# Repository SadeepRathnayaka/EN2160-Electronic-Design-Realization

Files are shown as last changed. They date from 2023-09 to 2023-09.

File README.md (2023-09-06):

# Semester 4 University Project - My Individual Work

## Introduction

Welcome to my semester 4 university project! This project represents my individual work, and it comes with several important features:

- **On/Off Switch:** There's a main switch that turns the product on and off.
- **Multimeter and Power Supply Modes:** Another switch allows you to switch between two modes: multimeter and 5V power supply.
- **Rotary Controls:** You'll find two rotary switches designed for mode selection and adjusting the ohmmeter's scale.
- **LED Display:** All the important readings are conveniently displayed on an LED screen.
- **Rechargeable Battery:** What makes this product special is its built-in rechargeable battery system. Say goodbye to constant battery replacements; this product includes an integrated charger mechanism.

<p align="center">
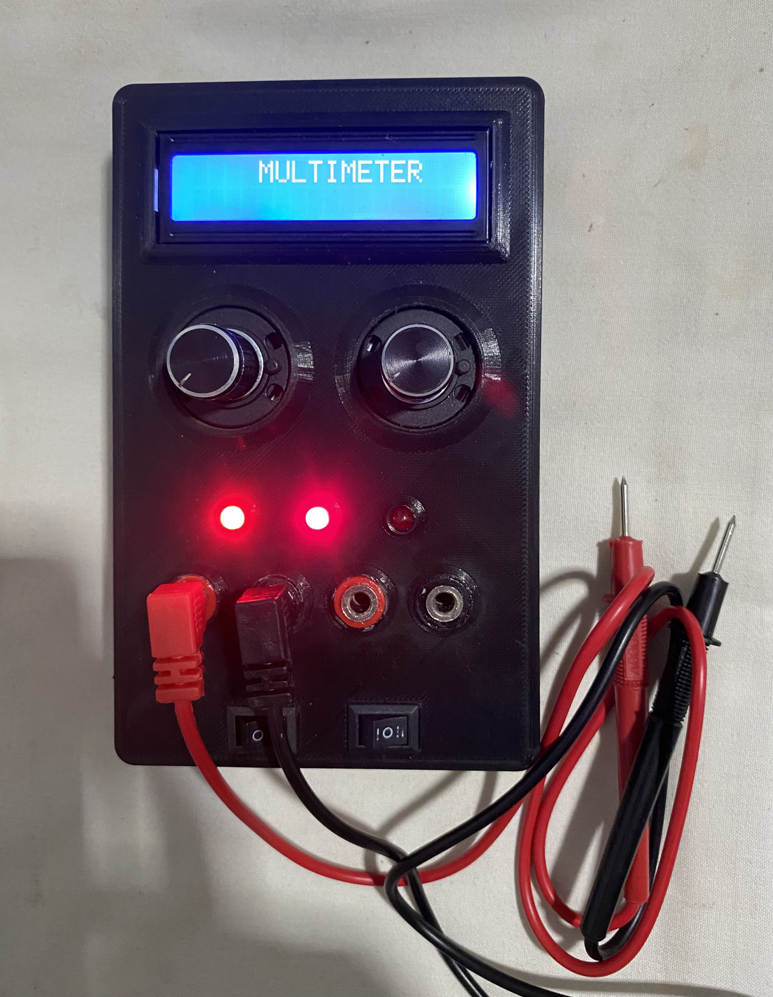
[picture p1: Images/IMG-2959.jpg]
  
</p>

## Specifications

- This product functions primarily as a multimeter and can also serve as a 5V DC power supply.
- The multimeter offers four distinct modes:

    1. Voltmeter
       - Measurement range: 0V to 50V

    2. Ammeter
       - Measurement range: 1mA to 2A

    3. Ohmmeter
       - Measurement range: 0 ohms to 1M ohms
       - It includes four resistance scales:
           - 0 to 1K ohms
           - 1K to 100K ohms
           - 100K to 400K ohms
           - 400K to 1M ohms

    4. Continuity Checker

- No need to change probes when switching to ammeter mode.
- This product features a charging capability, and when fully charged, it can operate continuously for up to 12 hours.
- A two-way switch allows easy mode switching between multimeter and power supply.
- Weight: 500g
- Dimensions: 13cm × 9cm × 2.5cm

  ## What You Can Find Here

- Component List
- Block Diagram
- Circuit Diagrams
- Schematics Designs
- PCB Designs
- Enclosure Design

*For more information, feel free to explore all the files and data in my repository. I've included comprehensive documentation, source code, and additional resources for a deeper dive into this project. Your feedback and contributions are highly appreciated.*

## Component List

- Atmega328p Microcontroller
- 3P4T Rotary Switches
- 16*2 LCD Display
- Single Pole Double Throw Switch
- On-Off Switch
- 1200mAh LiPo Battery
- TP4056 Charging Module
- MT3608 Boost Converter

## Block Diagram

<p align="center">
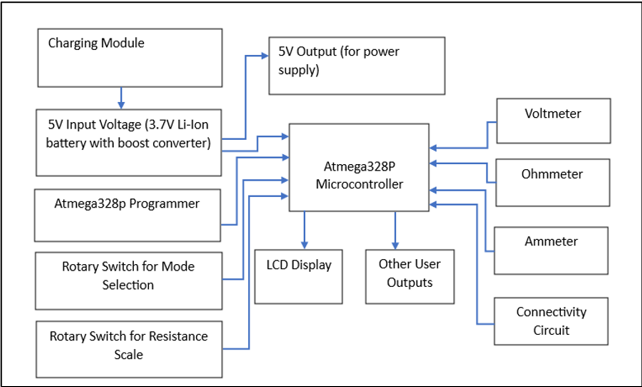
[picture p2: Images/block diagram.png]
  
</p>

## Circuit Diagrams

### Voltemeter
<p align="center">
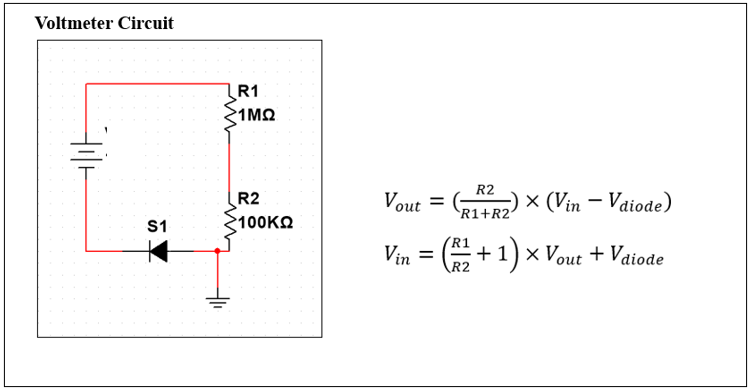
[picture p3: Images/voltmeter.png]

</p>

### Ohmmeter
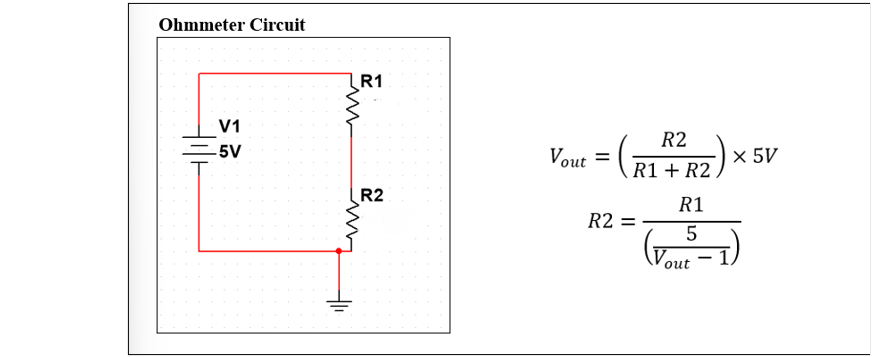
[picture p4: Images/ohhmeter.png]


### Ammeter
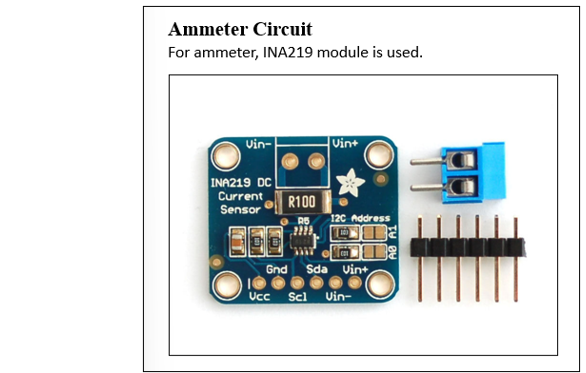
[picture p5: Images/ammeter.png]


## Schematic Designs 
<p align="center">
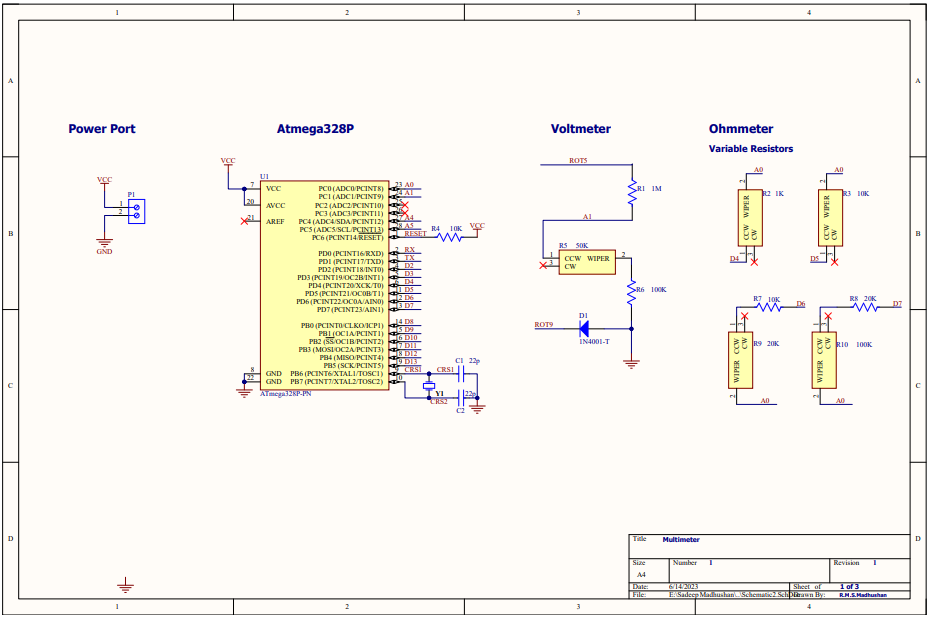
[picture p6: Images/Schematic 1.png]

</p>

<p align="center">
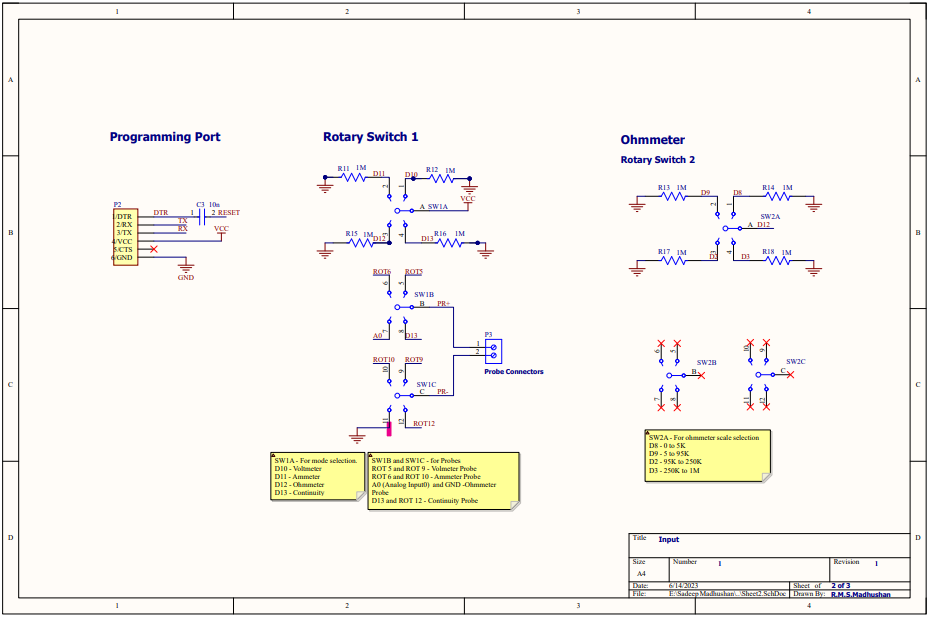
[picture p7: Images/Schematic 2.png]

</p>

<p align="center">
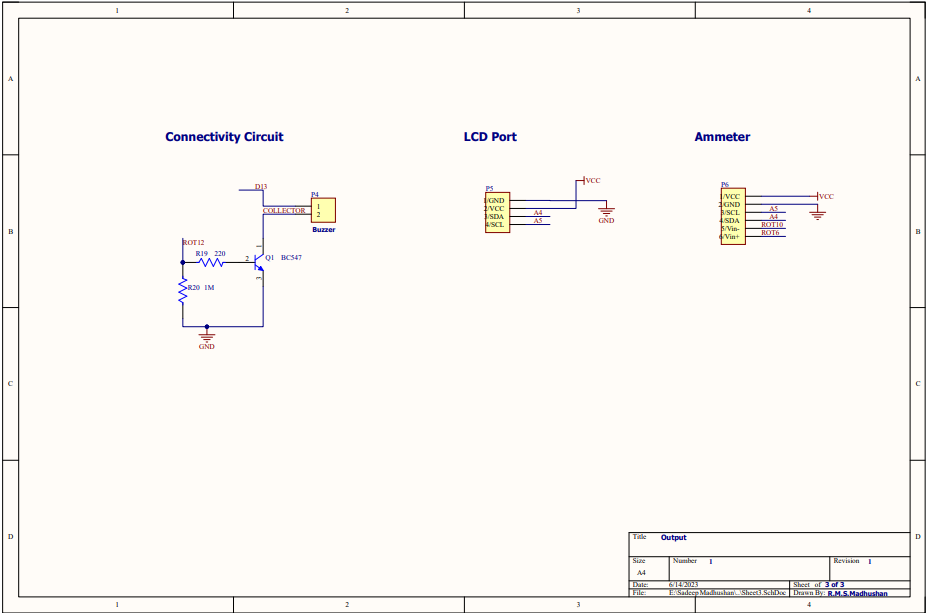
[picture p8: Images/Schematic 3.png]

</p>

## PCB Designs

<p align="center">
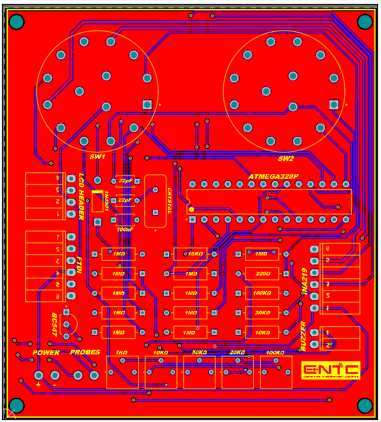
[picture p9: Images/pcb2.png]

</p>

<p align="center">
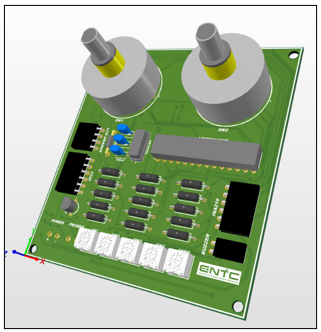
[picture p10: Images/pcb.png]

</p>

<p align="center">
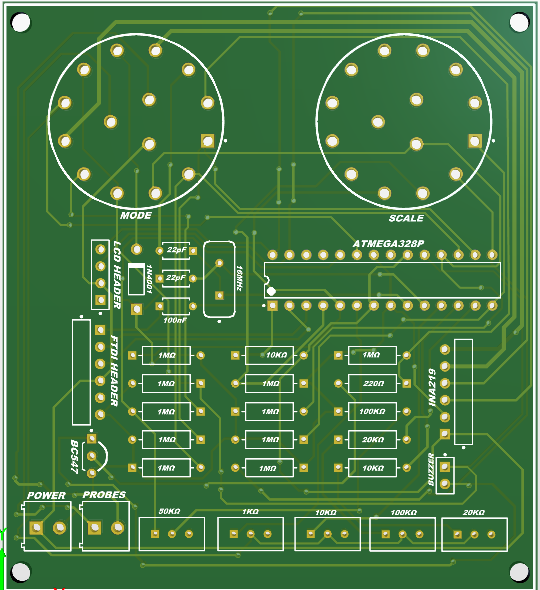
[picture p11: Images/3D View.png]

</p>

<p align="center">
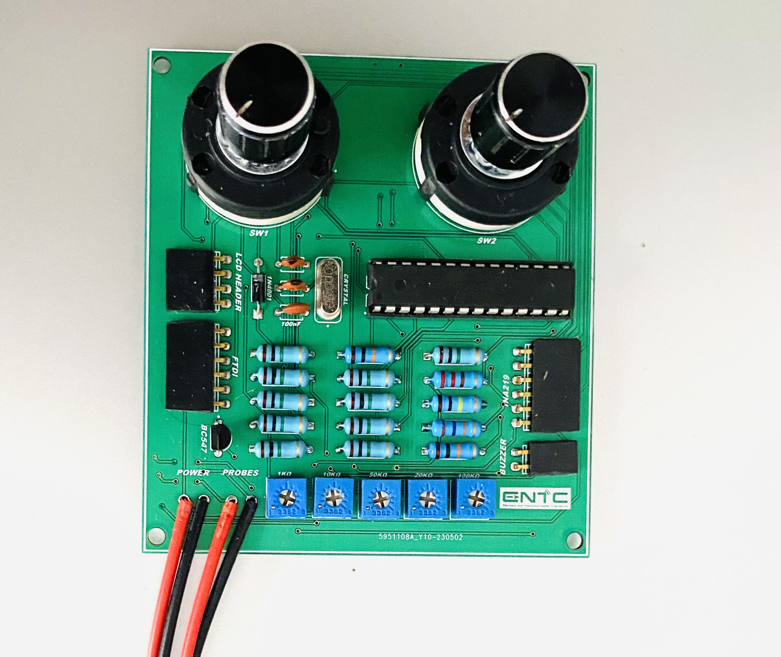
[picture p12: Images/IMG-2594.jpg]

</p>

## Enclosure Designs

<p align="center">
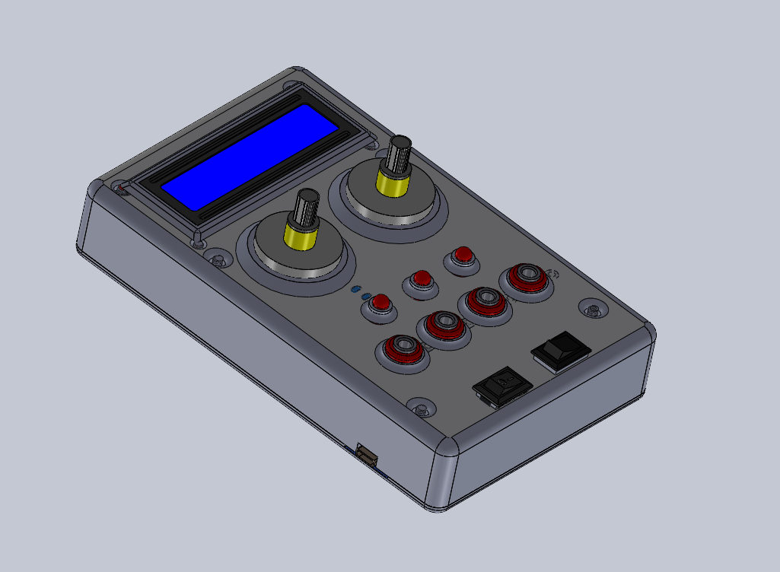
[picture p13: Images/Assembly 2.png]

</p>

<p align="center">
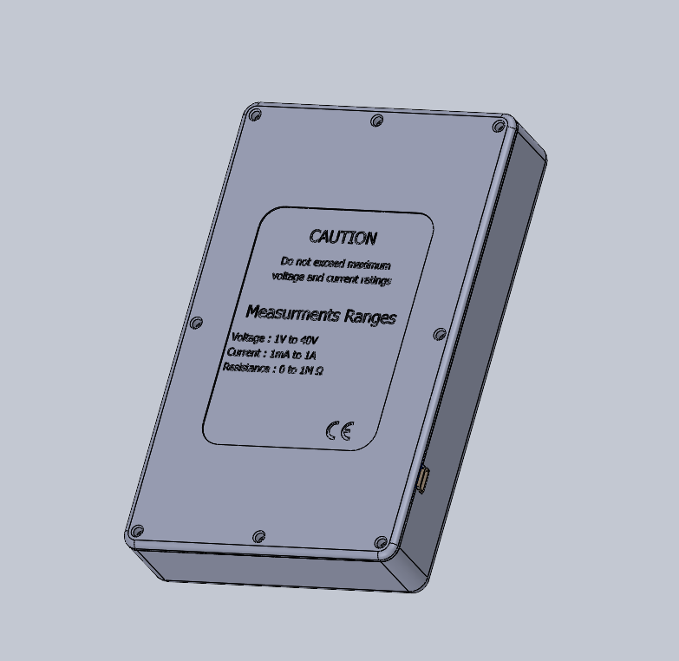
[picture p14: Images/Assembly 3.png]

</p>

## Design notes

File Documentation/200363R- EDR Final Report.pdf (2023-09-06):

1 | P a g e

## Department of Electronics and Telecommunication Engineering

Faculty of Engineering

University of Moratuwa

EN2160 Electronic Design Realization

Final Report

Madhushan R.M.S.

200363R

2 | P a g e

## Table of Contents

3 | P a g e

4 | P a g e

## General Information

Overview

The objective of the project was to create a commercially viable electronic product, incorporating novel functionalities to fulfill an existing demand. It is decided to make a digital multimeter which has a DC power supply compatibility as an extra feature. A multimeter, short for "multiple meter," is an indispensable tool in the realm of electrical and electronic measurements. This ingenious device serves as an all-in-one instrument, combining the functionalities of several meters into a single, compact unit. Its versatility makes it an essential companion for technicians, engineers, electricians, hobbyists, and anyone dealing with electrical circuits and systems.

In this fast-paced world of electronics and electrical engineering, the multimeter remains an enduring and vital instrument. As technology continues to evolve, these devices evolve too, incorporating innovative features and improvements to meet the ever-changing demands of the modern era. Whether you're a seasoned professional or an enthusiastic beginner, a multimeter is an invaluable asset, empowering you to confidently explore the intricacies of the electrical world.

Functionality

The focal attributes of this product comprise a primary switch and a two-way switch. The primary switch serves the purpose of activating or deactivating the product, while the second switch is responsible for seamlessly transitioning between the multimeter and 5V power supply modes. Additionally, the product incorporates two rotary switches, where one is designated for mode selection and the other is dedicated to adjusting the ohmmeter's scale. The readings obtained from the various functionalities are conveniently displayed through the utilization of an LED display. Notably, this product boasts a rechargeable battery system, eliminating the necessity for battery replacement, as it comes equipped with an integrated charger mechanism.

5 | P a g e

### Specifications

- This product is mainly a multimeter. Also this can be used as a 5V DC power supply.
- Multimeter has four modes.
1. Voltmeter
- Measurement range = 0V to 50V
2. Ammeter
a. Measurement range = 1mA to 2A
3. Ohmmeter
a. Measurement range = 0 ohm to 1M ohm
b. There are four resistance scales.
c. 0 to 1K ohm
d. 1K to 100K ohm
e. 100K to 400K ohm
f. 400K to 1M ohm
4. Continuity checker
- Probes do not have to change when it is working as an ammeter.
- This product has a charging feature.
- Once it is fully charged, it can be used 12 hours straight.
- There is a two way switch to change the mode between multimeter and power supply.
- weight = 500g
- Dimensions = 13cm × 9cm × 2.5cm

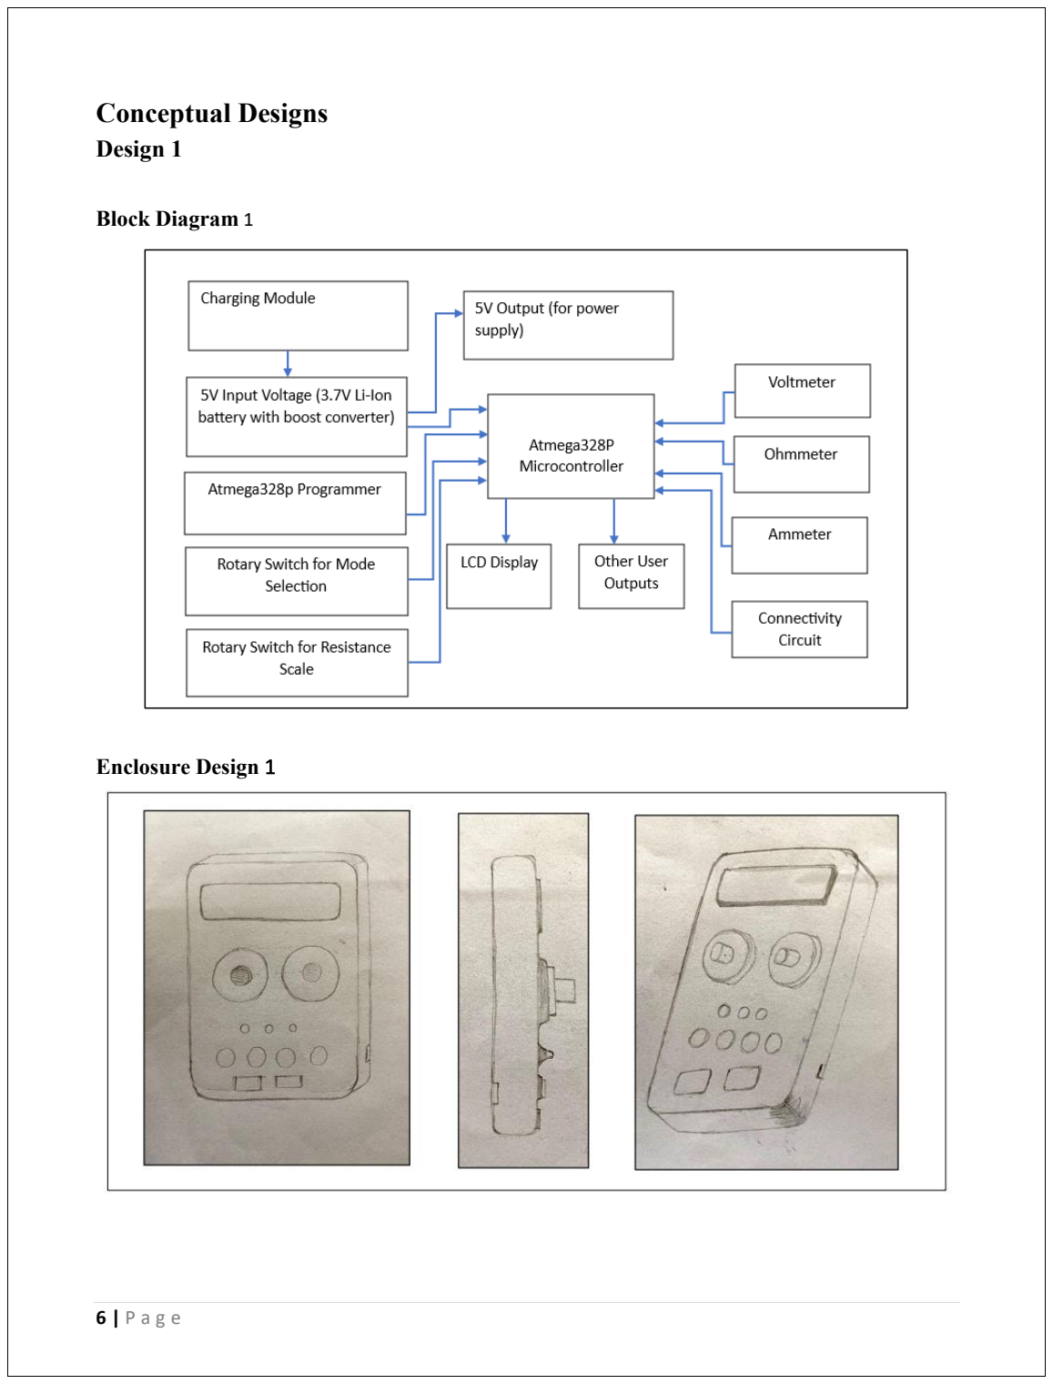
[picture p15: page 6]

6 | P a g e

### Conceptual Designs

Design 1

Block Diagram 1

Enclosure Design 1

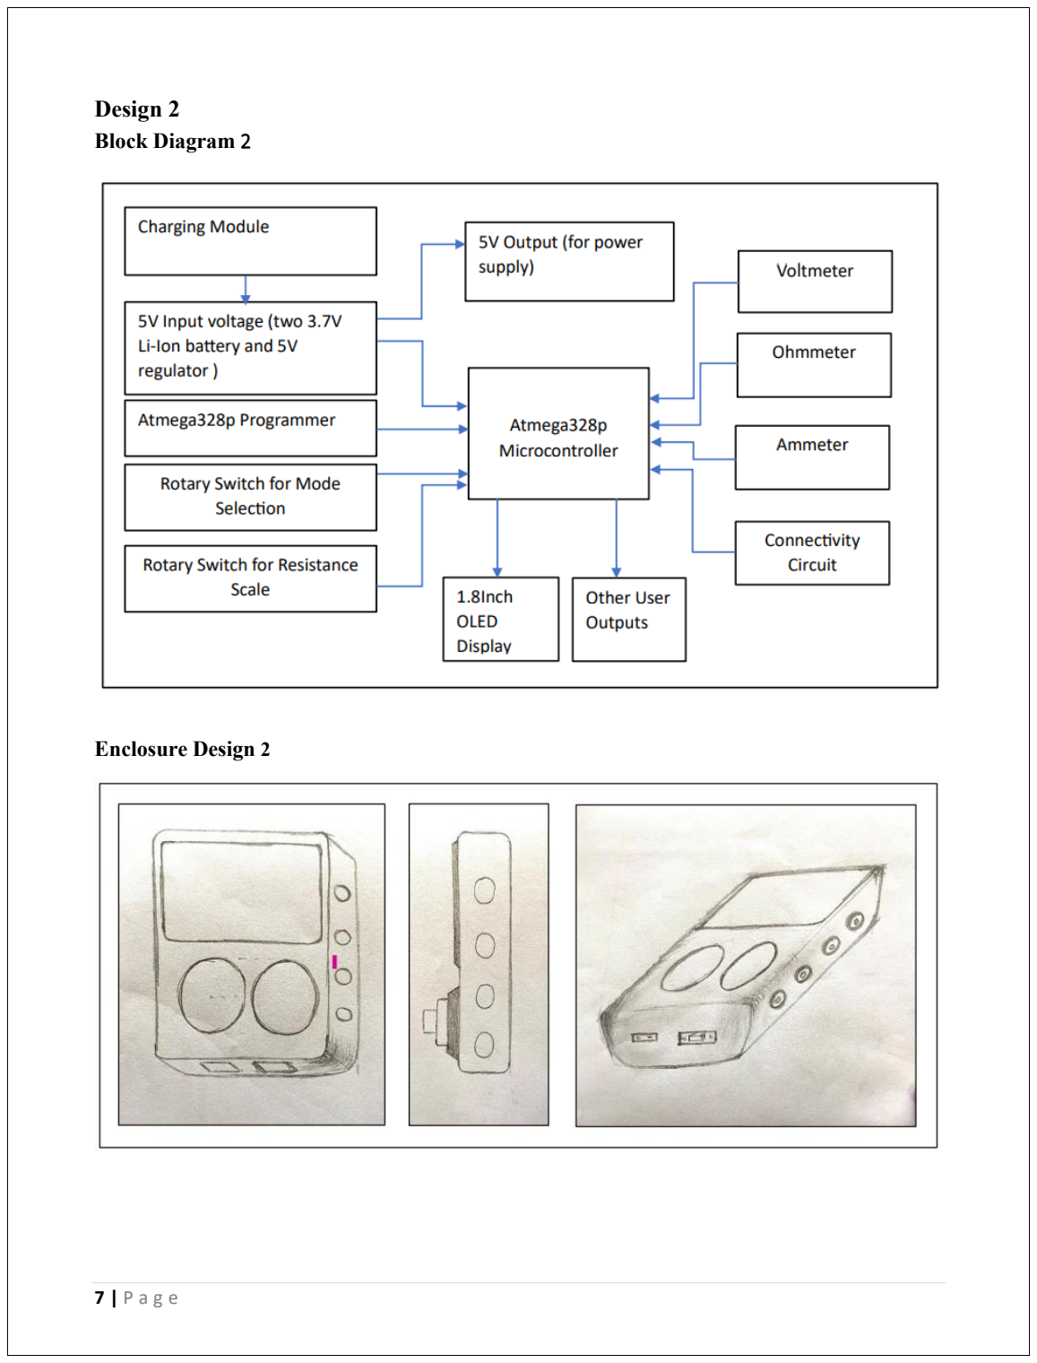
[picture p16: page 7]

7 | P a g e

Design 2
Block Diagram 2

Enclosure Design 2

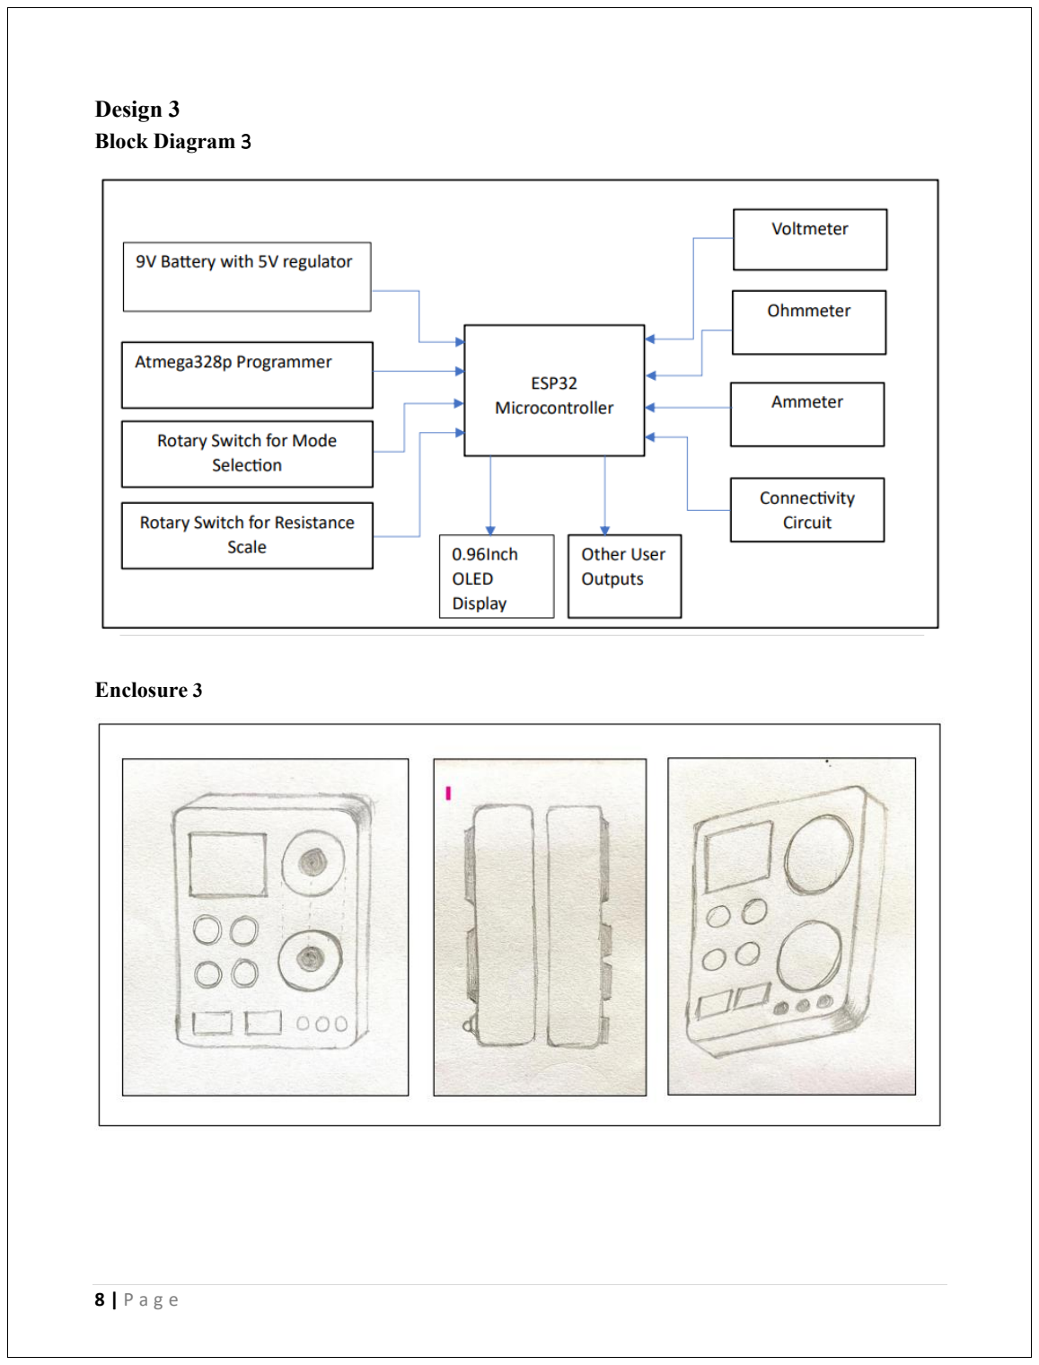
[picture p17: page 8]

8 | P a g e

Design 3
Block Diagram 3

Enclosure 3

9 | P a g e

### Comparison of Block Diagram 1 and 2

- Instead of one Li-Ion battery, two batteries are added to block diagram 2. Therefore, the total power that the circuit can utilize is higher than the 1st block diagram.
- Instead of using buck/boost converter, 5V voltage regulator is used since the regulator is inexpensive when compared buck/boost converter which is used in block diagram 1.
- In this design, a much larger OLED display is used compared to block diagram 1.

### Comparison of Block Diagram 1 and 3

- 5V Power supply option is removed in the design.
- The charging feature is removed.
- One 9V battery is used compared to block diagram 1.
- A smaller OLED display is used in this block diagram.
- Buck/boost converter is not used to reduce the cost.

10 | P a g e

Evaluation
Evaluation of Block Diagram Criteria :
1) Functionality
2) Accuracy
3) User Friendliness
4) Cost
5) Power Consumption
6) Reliability
7) Compatibility – (Capability of replacing device or systems that perform the same process or part of the process)
| Block Diagram 1 | Block Diagram 2 | Block Diagram 3
Functionality | 10 | 9 | 9
Accuracy | 9 | 8 | 8
User Friendliness | 9 | 7 | 7
Cost Effectiveness | 8 | 7 | 9
Power Efficiency | 8 | 8 | 9
Reliability | 9 | 9 | 9
Compatibility | 7 | 7 | 7
Total | 59 | 55 | 58

Evaluation of Enclosure Design Criteria :

1) Durability
2) Attractiveness
3) Cost Effectiveness
4) User Safety – Prevention from electric leakage
5) Compatibility – Capability of attaching the device to a certain place
6) Repairability
7) Weight and Hardness
| Enclosure 1 | Enclosure 2 | Enclosure 3
Durability | 9 | 9 | 9
Attractiveness | 8 | 7 | 7
Cost Effectiveness | 8 | 7 | 8
User Safety | 8 | 8 | 8
Compatibility | 8 | 7 | 8
Repairability | 8 | 5 | 7
Weight and Hardness | 8 | 8 | 8
Total | 57 | 51 | 55
According to the evaluation, block diagram 1 and enclosure design 1 has been chosen.

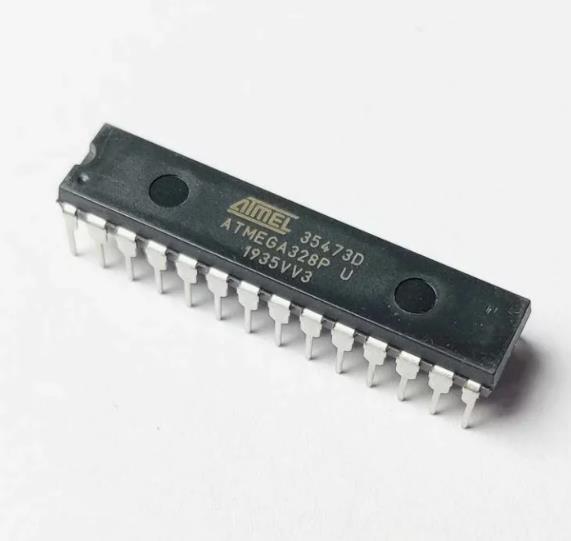
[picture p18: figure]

11 | P a g e

## Components

Atmega328P Microcontroller

The ATmega328P is a widely used 8-bit microcontroller from the AVR family, manufactured by Atmel (now Microchip Technology). It offers a versatile and efficient solution for a wide range of embedded systems and DIY electronics projects. With a clock speed of up to 20 MHz, it can handle tasks quickly and precisely. The microcontroller comes equipped with 32KB of Flash memory for storing program code, 2KB of SRAM for temporary data storage, and 1KB of EEPROM for non-volatile data storage. Its GPIO pins allow for flexible interfacing with external devices, while the built-in 10-bit ADC enables the conversion of analog signals to digital values. Additionally, the ATmega328P features multiple timers and counters, which are valuable for generating accurate timing, PWM signals, and event counting. Its popularity and ease of use make it a favored choice among hobbyists, engineers, and developers seeking a reliable microcontroller for their projects.

All voltmeter, ammeter, ohmmeter, continuity checker circuits are connected to the relevant pins of this microcontroller. Once it is set to the appropriate state for the ammeter, volmeter, ammeter ohmmeter, continuity checker, the microcontroller will send the reading to the display.

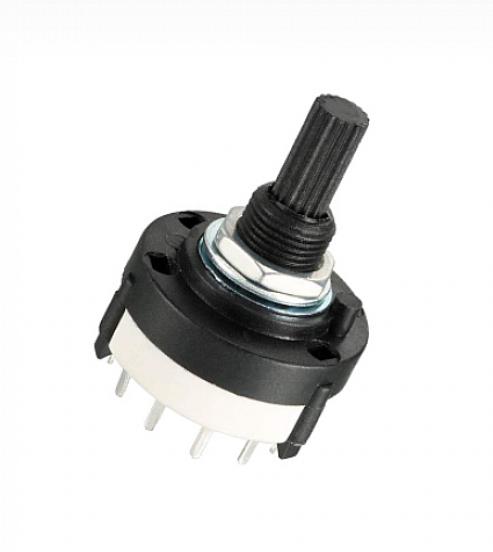
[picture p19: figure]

12 | P a g e

Rotary Switch

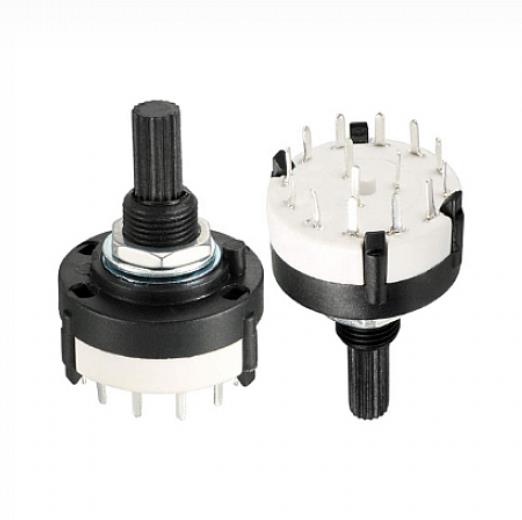
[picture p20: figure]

The 3P4T switch is a rotary switch commonly used in electronics. It has three poles, allowing control of three separate circuits, and four positions, enabling the selection of different circuit combinations with a single actuator. This switch is frequently employed in devices like audio equipment and electronic instruments for straightforward and reliable circuit switching.

In this product, two 3 pole 4 state switches are used. One is for multimeter modes and for the other one is for resistance scale.

The mode selection rotary switch has four modes.

1. Voltmeter
2. Ammeter
3. Ohmmeter
4. Continuity Checker

When the modes are changed, corresponding probes connection also changes accordingly. Therefore the user does not have to change the probes when the mode is being changed.

Resistance scale rotary switch has four scales.

1. 1K ohm
2. 100K ohm
3. 400K ohm
4. 1M ohm

13 | P a g e

LCD Display

The 16x2 LCD display is a widely used alphanumeric display module in the field of electronics and embedded systems. It consists of 16 columns and 2 rows, providing a total of 32 characters (16 characters per row) that can be displayed at once. Each character position is typically composed of a 5x8 dot matrix, allowing the display of letters, numbers, symbols, and simple graphics.

Single Pole Double Throw Switch

A Single-Pole, Double-Throw (SPDT) switch is a basic and commonly used type of electrical switch. It consists of a single input terminal (pole) and two output terminals (throws). When in the "ON" position, the common terminal connects to one of the two output terminals, and when in the "OFF" position, it disconnects from the first output and connects to the second one. This simple but versatile configuration allows SPDT switches to toggle between two different circuits, making them suitable for various applications, such as controlling lights, motors, and electronic devices.

This switch is used to change the mode between multimeter and 5V DC power supply.

14 | P a g e

Battery

The LiPo (Lithium Polymer) 1200mAh battery is a compact and lightweight rechargeable power source widely used in portable electronics and hobbyist projects. With a capacity of 1200 milliampere-hours (mAh), it can supply a steady electric current of 1.2 Amps for one hour, or proportional current over a longer duration. This outputs 3.7V.

Instead of 18650 Li-Ion 1200mAh battery, it is decided use this battery. Main reason for that is the size of this battery. It is a compact battery so that the product size also can be more small.

Charging Module

The TP4056 is a popular and widely used single-cell lithium battery charging module. It is designed to charge lithium-ion (Li-ion) and lithium-polymer (LiPo) batteries safely and efficiently. This compact module integrates a charging chip, power management components, and status indicator LEDs into a single package, making it convenient for charging applications. Therefore this module has been chosen for the charging module for the device.

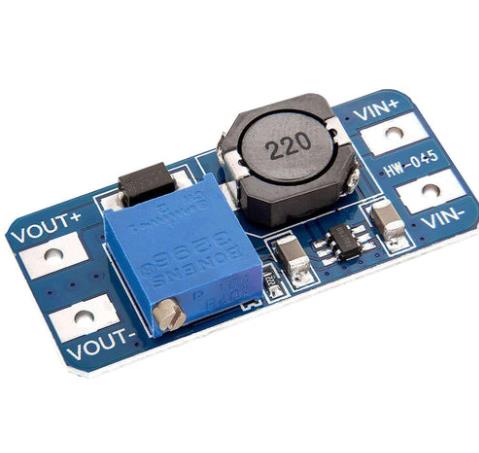
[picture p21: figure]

15 | P a g e

Boost Converter

The MT3608 is a versatile and widely used DC-DC boost converter module designed to step up voltage levels efficiently. Since Li-Po battery only output 3.7V it should be convert to 5V. In order to do that, this module has been chosen.

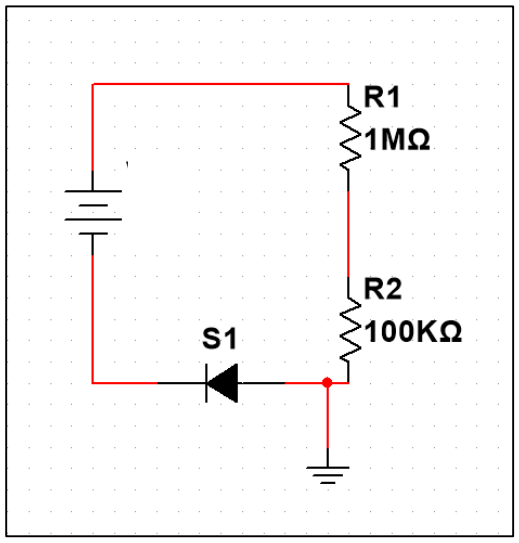
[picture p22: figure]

16 | P a g e

## Circuit Diagrams

Voltmeter Circuit

- In this circuit, R1 and R2 are chosen in such a way that the voltage measuring range can be

maintained around 50V.

- 1N4001 diode is used to block the current to the other direction.
- Here V1 act as the voltage source we want to measure the voltage.
- When V1 is set, there is a voltage drop across the R2 resistor and that voltage drop is measured

from analog input pin from atmega328p microcontroller.

- After taking that Vout value, according to the above calculation Vin can be found.

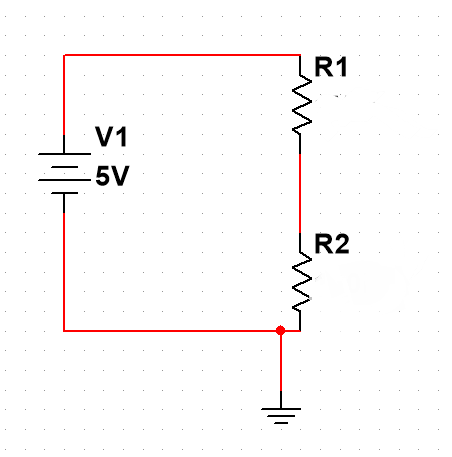
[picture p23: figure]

17 | P a g e

Ohmmeter Circuit

- R2 is the unknown resistor.
- There are four R1 resistors chosen according to various scale.
- 1K, 10K, 50K and 100K are the R1 resistor values.
- According to the R2 value user can set the corresponding R1 value with a rotary switch and then

more precisely resistance can be measured.

- 5V is being supplied from the atmega328p microcontroller.
- After supplying that voltage, there is a corresponding voltage drop across R2 and that will be

measured from analog input of the atmega328p microcontroller.

- Then according to the above calculation, R2 can be found.

18 | P a g e

Ammeter Circuit
For ammeter, INA219 module is used.

The primary functionality of the INA219 is current sensing. It is specifically designed to accurately measure the current flowing through a load in electrical systems. This is achieved through a high-side current shunt resistor incorporated within the IC.

When current flows through the load, a voltage drop occurs across the shunt resistor. The INA219 measures this voltage drop with high precision. By utilizing Ohm's law (V = I * R), where V is the voltage across the shunt resistor, I is the current flowing through the load, and R is the resistance of the shunt, the INA219 calculates the current value.

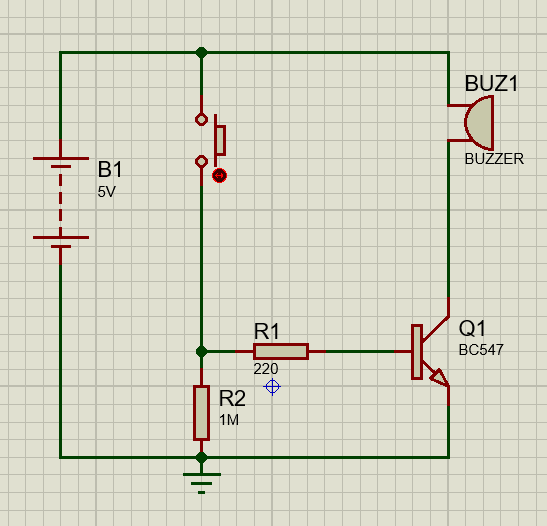
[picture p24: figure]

19 | P a g e

Continuity Checker Circuit

- Instead of push button, two probes are set there.
- therefore when there is connection between those two probes, circuit will be fully connected.
- Then, there will be base current and the transistor will act as a closed switch and buzzer will be

on.

## Schematic Design

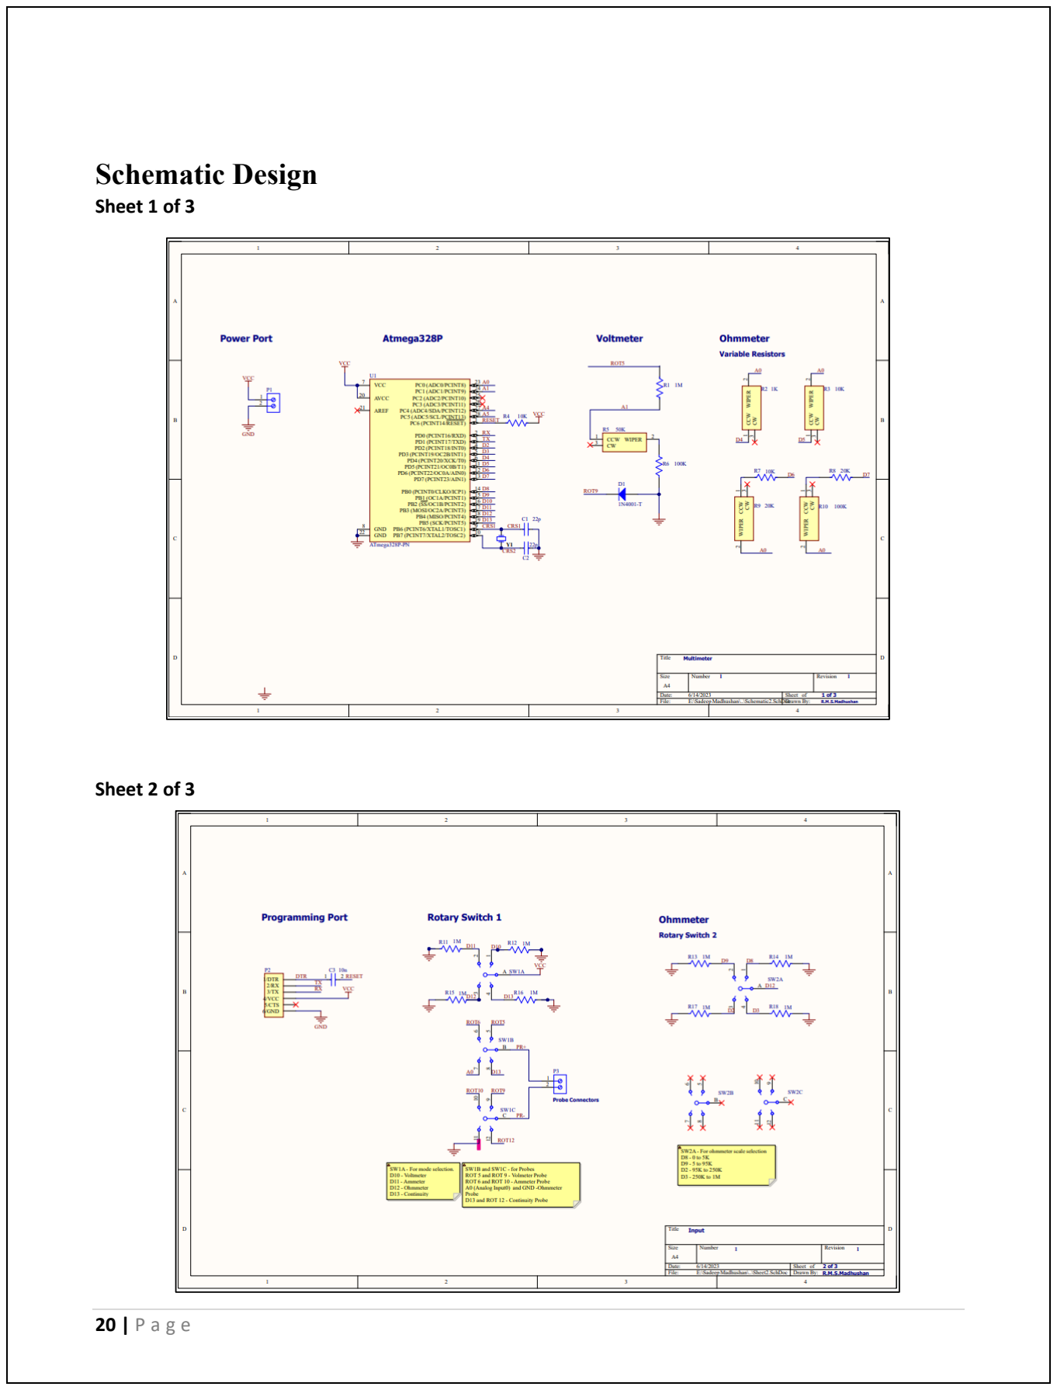
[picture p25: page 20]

20 | P a g e

Sheet 1 of 3

Sheet 2 of 3


21 | P a g e

Sheet 3 of 3

22 | P a g e

## Printed Circuit Board

Gerber Files Details
Top Layer Gerber Data

Top Overlay Gerber Data

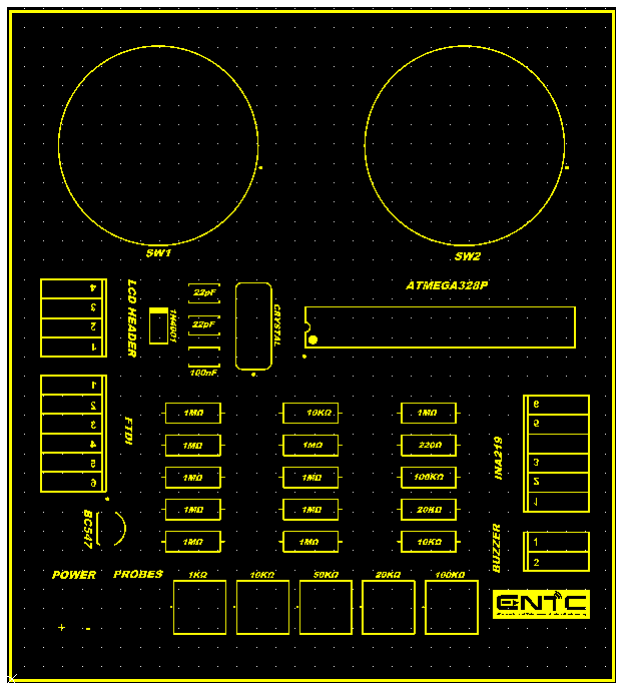
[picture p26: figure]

23 | P a g e

Top Solder Mask Gerber Data

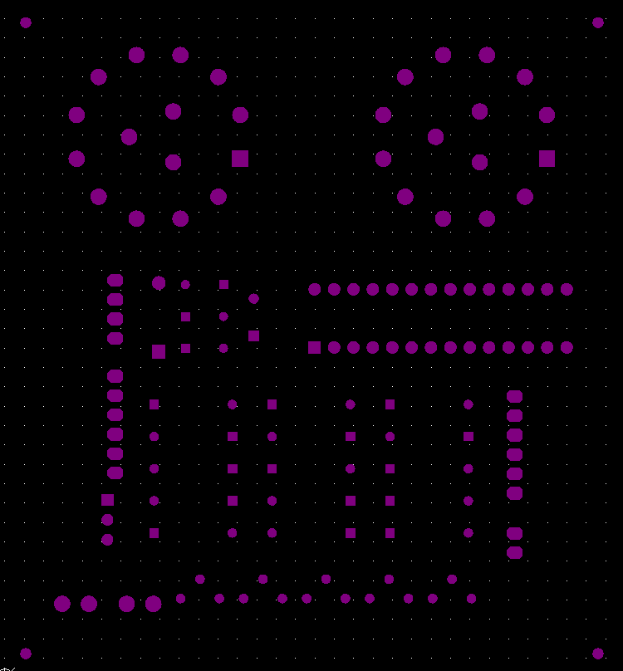
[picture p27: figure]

Bottom Layer Gerber Data

24 | P a g e

Bottom Solder Mask Gerber Data

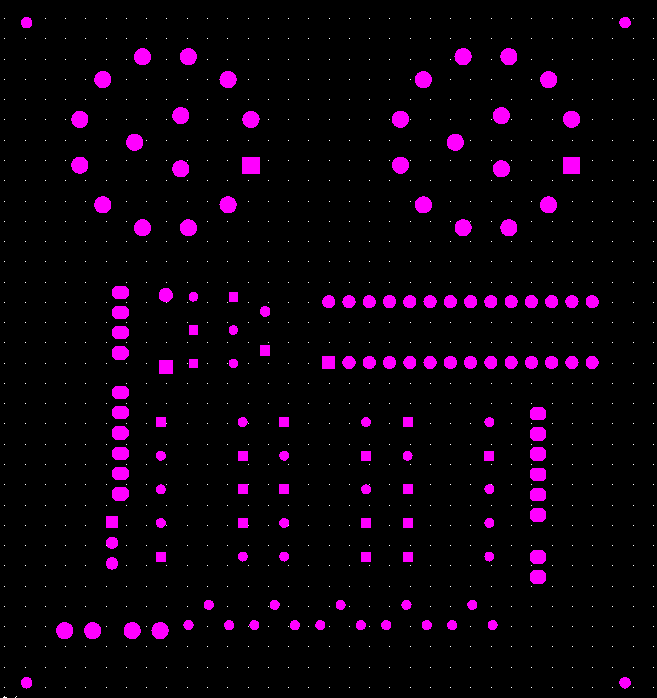
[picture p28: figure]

Drill Drawing Layer Pair Gerber Data

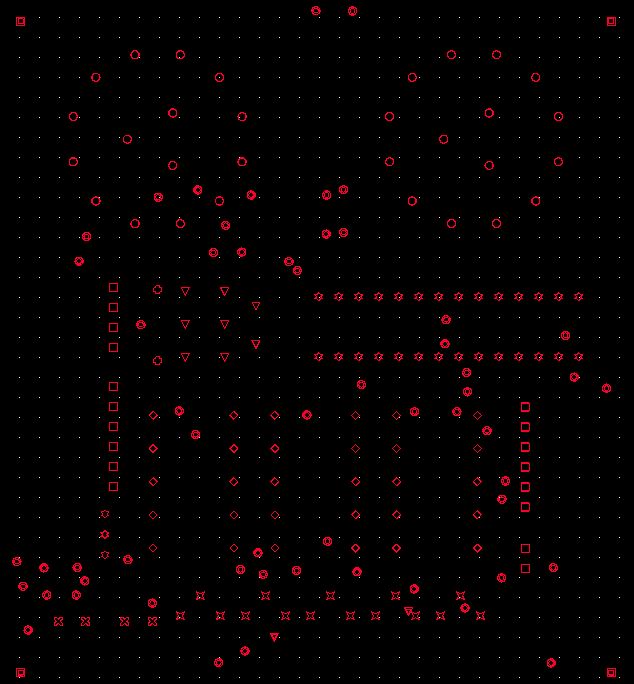
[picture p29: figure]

25 | P a g e

2D View

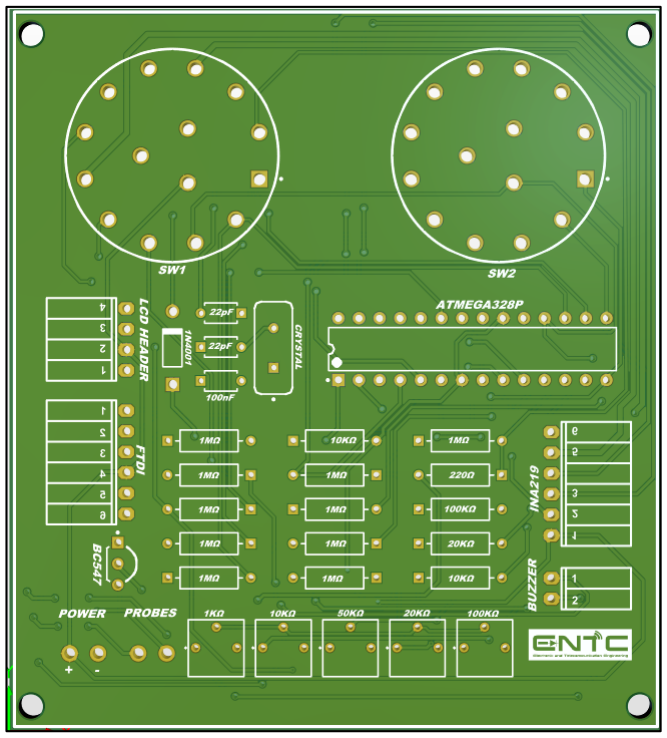
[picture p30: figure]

26 | P a g e

3D View

After Soldering:

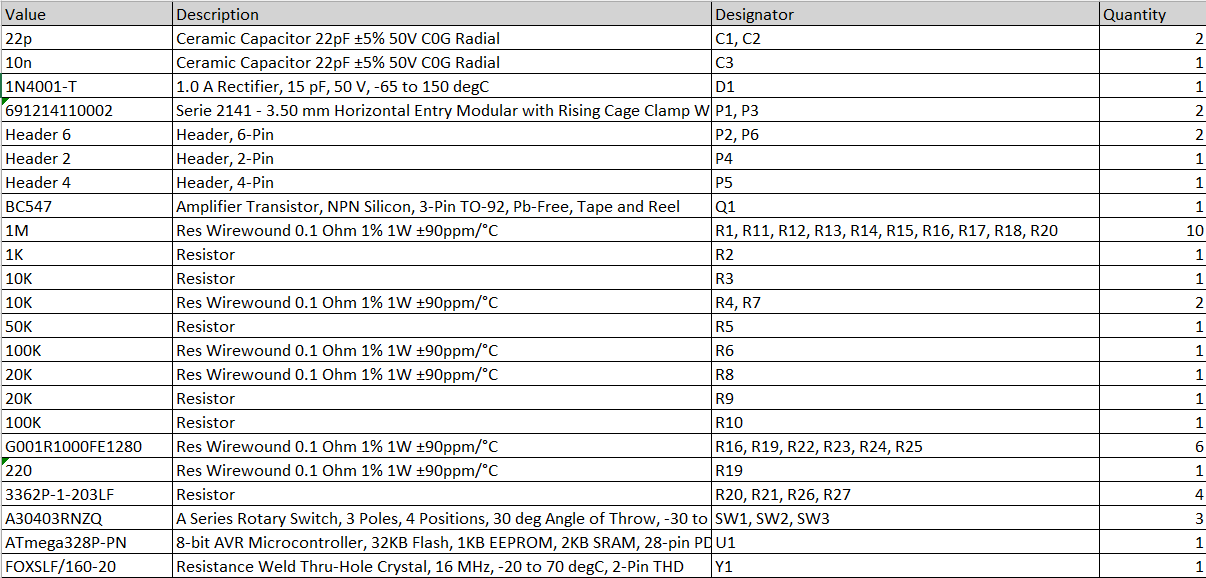
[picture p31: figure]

27 | P a g e

Bill of Materials

28 | P a g e

## Suppliers and Manufacturers

Component | Quantity | Manufacturer | Supplier | Price (LKR)
22pF Capacitor | 2 | | Local Supplier | 10
1M Resistors | 10 | | Local Supplier | 50
1K Resistors | 1 | | Local Supplier | 5
10K Resistors | 3 | | Local Supplier | 15
20K Resistors | 1 | | Local Supplier | 5
50K Resistors | 1 | | Local Supplier | 5
100K Resistors | 1 | | Local Supplier | 5
1K Preset Potentiometer | 1 | Bochen | LCSC Electronics | 20
10K Preset Potentiometer | 1 | Bochen | LCSC Electronics | 20
20K Preset Potentiometer | 1 | Bochen | LCSC Electronics | 20
50K Preset Potentiometer | 1 | Bochen | LCSC Electronics | 20
120K Preset Potentiometer | 1 | Bochen | LCSC Electronics | 20
Atmega328P | 1 | Microchip Technology | Mouser Electronics | 2000
16MHz Oscillator | 1 | | Local Supplier | 20
BC547 Transistor | 1 | | Local Supplier | 5
3P4T Rotary Switch | 2 | | Local Supplier | 600
1N4001 Diode | 1 | | Local Supplier | 5
INA219 Sensor | 1 | Adafruit | Mouser Electronics | 3000
TP4056 Module | 1 | | Local Supplier | 160
3.7V Li-Po Battery | 1 | TinyCircuits | Mouser Electronics | 2000
MT3608 Boost Converter | 1 | | Local Supplier | 280
LCD Display | 1 | | Local Supplier | 700
SPDT Switch | 1 | | Local Supplier | 20
On-off switch | 1 | | Local Supplier | 10
JST cables and other wires | | | Local Supplier | 300

## Enclosure

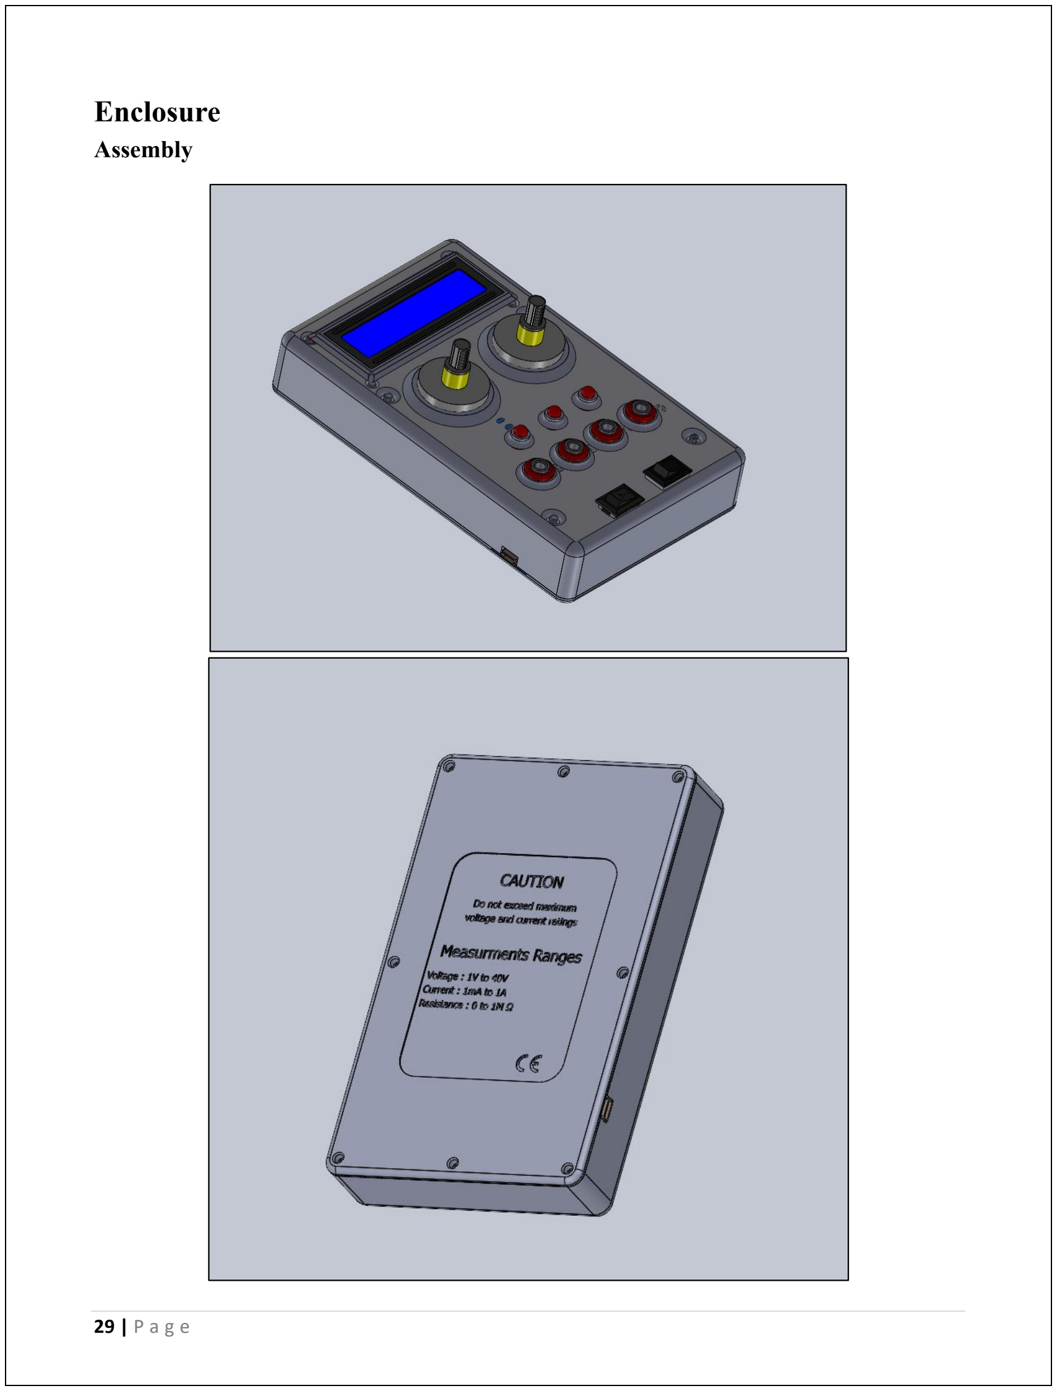
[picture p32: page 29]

29 | P a g e

Assembly

30 | P a g e

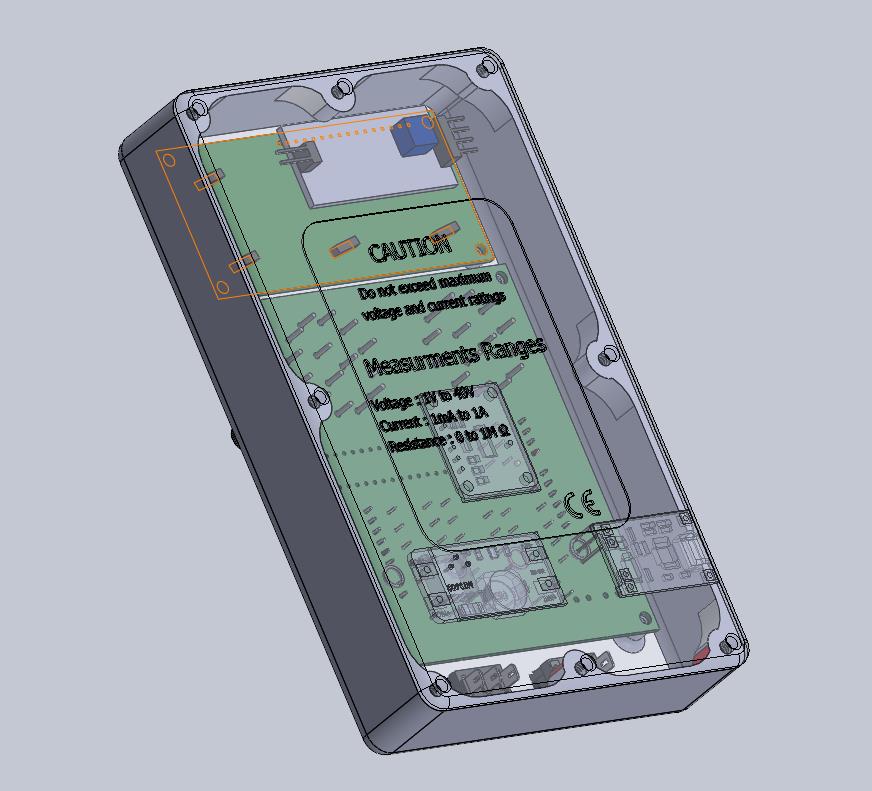
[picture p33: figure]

31 | P a g e

Top Cover

Bottom Cover

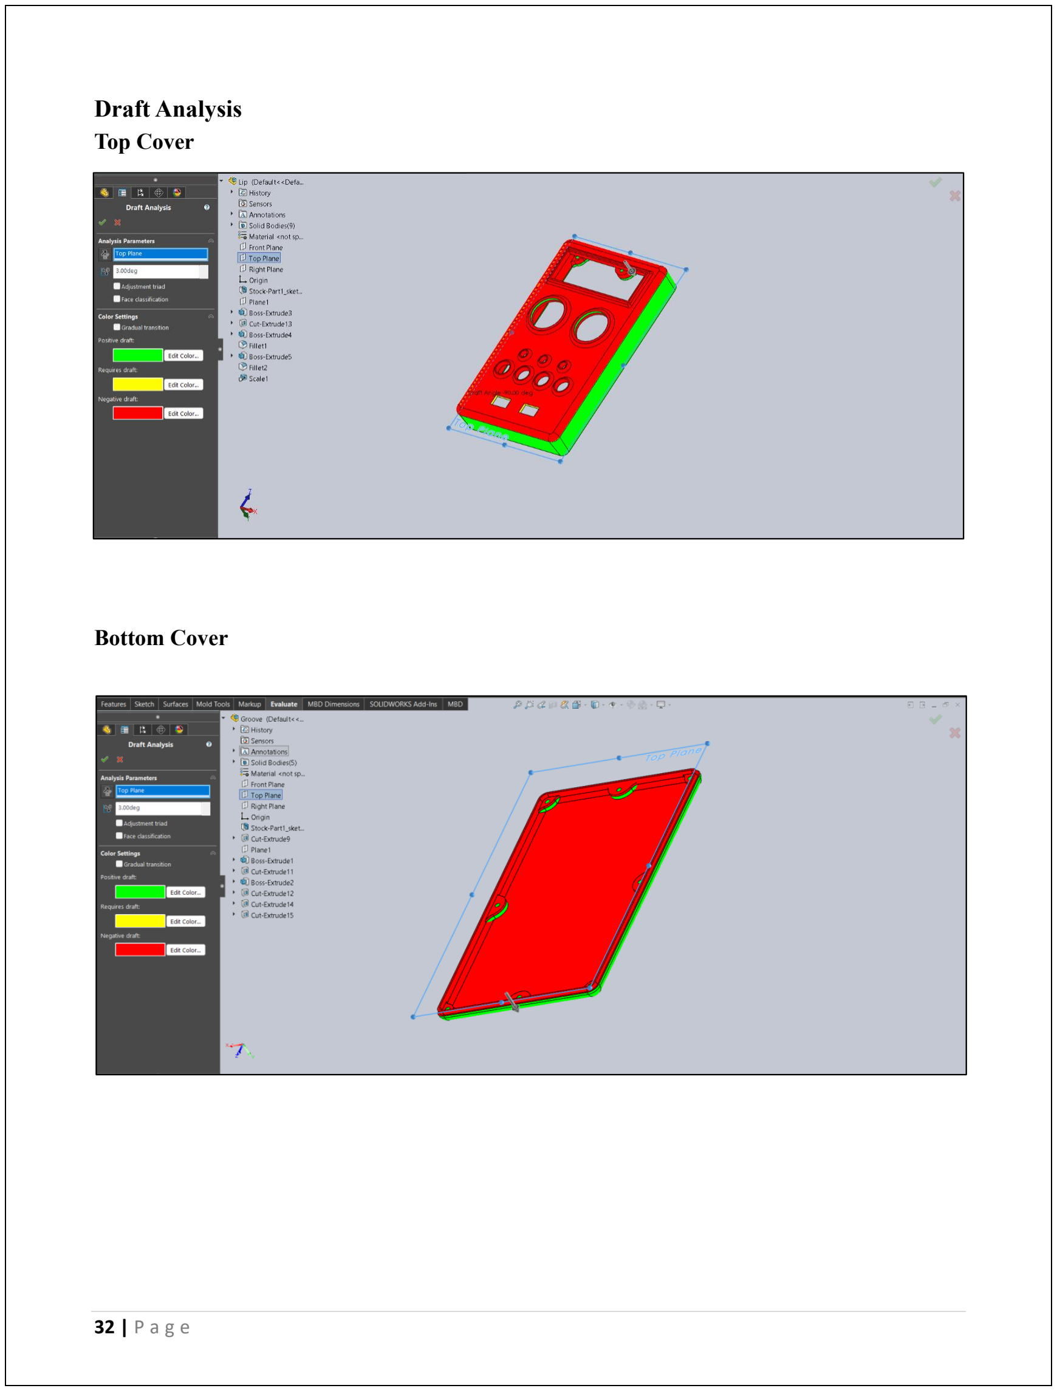
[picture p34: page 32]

32 | P a g e

Draft Analysis
Top Cover

Bottom Cover

33 | P a g e

## Manufacturing Details

PCB Manufacturing

PCB Manufacturer: Jia Li Chuang (Hong Kong) Co., Limited (JLC PCB)

PCB Specifications

- Base Material : FR-4
- Layer : 2
- Dimensions : 79.19mm * 87.33mm
- PCB Color : Green
- Silkscreen Color : White
- Surface Finish : HASL(with lead)
- Copper weight : 1 oz
- For PCB Manufacturing, the total cost : 3000LKR (with TAX and shipping cost)

Enclosure Manufacturing

- Prototype has been 3D printed locally.
- For mass production it must be used injection molding.
- Enclosure Manufacturing, total cost : 6500LKR

Cost
- Cost for PCB = 3000
- Cost for enclosure = 6000
- Cost for components = 10000
- For the prototype, total cost = 3000 + 6000 + 10000 = 19000 LKR
- When mass producing for the enclosure estimated cost (by using injection molding) = 20 LKR
- When mass producing for the PCB estimated cost = 200 LKR
- For components = 500 LKR
- Total cost = 720 LKR

Estimated Price when it releases to the market = 1000LKR

34 | P a g e

## Code

- Coding is done by Arduino Programming Language.
- The printed circuit board (PCB) is equipped with a designated port intended for interfacing with the FTDI module, facilitating the programming of the atmega328p microcontroller. By utilizing this port, the programming process is efficiently accomplished.

#include <Wire.h>

#include <Adafruit_INA219.h>

#include <LiquidCrystal_I2C.h>3

#define INA219_ADDRESS 0x40

#define LCD_ADDRESS 0x27

int delay_time = 100;

LiquidCrystal_I2C lcd(LCD_ADDRESS,16,2);

Adafruit_INA219 ina219;

////////////////////////////////////////// Mode Rotary Switch Inputs /////////////////////////////////////

int VOLTMETER = 10;

int AMMETER = 11;

int OHMMETER = 12;

int CONTINUITY = 13;

////////////////////////////////////////// ohmmeter ///////////////////////////////////////////////////////

// rotary switch inputs

int R1K_input = 8 ; // 0 - 5K

int R10K_input = 9 ; // 5K - 40K

int R27K_input = 2 ; // 40K - 100K

int R100K_input = 3 ; // 100K - 450K

// selecting scale pins

int R1K_output = 4 ;

int R10K_output = 5 ;

35 | P a g e

int R27K_output = 6 ;

int R100K_output = 7 ;

// resistors values

float R1K = 1.0;

float R10K = 10.0 ;

float R27K = 30.0 ;

float R100K = 120.0 ;

///////////////////////////////////// end of ohmmeter ///////////////////////////////////////////////////

////////////////////////////////////////Voltmeter //////////////////////////////////////////////////////

int res1_vol = 1000 ;

int res2_vol = 100 ;

int diode_val = 0.6 ;

//////////////////////////////////////End of Voltmeter /////////////////////////////////////////////////

// reference voltage given from buck converter

int Vref = 5;

// constants oh ohmmeter

float Vout_ohm, new_Vout_ohm, Vref_div_newVout_ohm, R2 ;

void setup() {

// analog reference and lcd displlay initializing

lcd.init();

lcd.backlight();

lcd.clear();

lcd.setCursor(4,0);

lcd.print("MULTIMETER");

delay(3000);

36 | P a g e

////////////////////////////// INA219 initializing ///////////////////////////

Serial.begin(115200);

while (!Serial) {

// will pause Zero, Leonardo, etc until serial console opens

delay(1);

}

if (! ina219.begin()) {

Serial.println("Failed to find INA219 chip");

while (1) { delay(10); }

}

// Serial.println("Measuring voltage and current with INA219 ...");

/////////////////////////////////End of INA219 /////////////////////////////////////

// Mode Rotary Switch pins initializing

pinMode(VOLTMETER,INPUT);

pinMode(AMMETER,INPUT);

pinMode(OHMMETER,INPUT);

pinMode(CONTINUITY,INPUT);

// ohmmeter pins intializing

pinMode(R1K_input,INPUT);

pinMode(R10K_input,INPUT);

pinMode(R27K_input,INPUT);

pinMode(R100K_input,INPUT);

pinMode(R1K_output,INPUT);

pinMode(R10K_output,INPUT);

pinMode(R27K_output,INPUT);

pinMode(R100K_output,INPUT);

37 | P a g e

pinMode(A0, INPUT); // Vout_ohm reading pin

// end of ohmmeter initializing

}

void loop() {

if (digitalRead(VOLTMETER) == HIGH) {

Serial.println("voltmeter");

pinMode(VOLTMETER,INPUT);

pinMode(AMMETER,OUTPUT);

pinMode(OHMMETER,OUTPUT);

pinMode(CONTINUITY,OUTPUT);

lcd.clear();

lcd.setCursor(4,0);

lcd.print("VOLTMETER");

delay(1000);

while (true) {

voltmeter();

if (digitalRead(VOLTMETER) != HIGH) {

delay(delay_time);

break;}

}

}

if (digitalRead(AMMETER) == HIGH) {

Serial.println("ammeter");

pinMode(VOLTMETER,OUTPUT);

pinMode(AMMETER,INPUT);

pinMode(OHMMETER,OUTPUT);

pinMode(CONTINUITY,OUTPUT);

lcd.clear();

38 | P a g e

lcd.setCursor(4,0);

lcd.print("AMMETER");

while (true) {

ammeter();

if (digitalRead(AMMETER) != HIGH) {

delay(delay_time);

break;}

}

}

if (digitalRead(OHMMETER) == HIGH) {

Serial.println("OHMmeter");

pinMode(VOLTMETER,OUTPUT);

pinMode(AMMETER,OUTPUT);

pinMode(OHMMETER,INPUT);

pinMode(CONTINUITY,OUTPUT);

lcd.clear();

lcd.setCursor(4,0);

lcd.print("OHMMETER");

delay(1000);

while (true) {

ohmmeter();

if (digitalRead(OHMMETER) != HIGH) {

delay(delay_time);

break;}

}

}

if (digitalRead(CONTINUITY) == HIGH) {

Serial.println("continuity");

39 | P a g e

pinMode(VOLTMETER,OUTPUT);

pinMode(AMMETER,OUTPUT);

pinMode(OHMMETER,OUTPUT);

pinMode(CONTINUITY,INPUT);

lcd.clear();

lcd.setCursor(4,0);

lcd.print("CONTINUITY");

lcd.setCursor(4,1);

lcd.print("CHECKER");

delay(1000);

while (true) {

if (digitalRead(CONTINUITY) != HIGH) {

delay(delay_time);

break;}

}

}

}

void ohmmeter() {

// 0 - 1K

if (digitalRead(R1K_input) == HIGH) {

pinMode(R1K_output,OUTPUT);

pinMode(R10K_output,INPUT);

pinMode(R27K_output,INPUT);

pinMode(R100K_output,INPUT);

digitalWrite(R1K_output, HIGH);

R2 = 0 ;

for (int i=0; i < 1000; i++) {

40 | P a g e

Vout_ohm = analogRead(A0);

new_Vout_ohm = (Vout_ohm*Vref) / 1024 ;

Vref_div_newVout_ohm = Vref / new_Vout_ohm ;

R2 += (R1K) / (Vref_div_newVout_ohm - 1) ;}

R2 = R2/1000.0 ;

Serial.print("1K ");

Serial.println(new_Vout_ohm);

if (new_Vout_ohm > 4.2) {

lcd.clear();

lcd.setCursor(0,0);

lcd.print("Increase scale /");

lcd.setCursor(0,1);

lcd.print("Change Resistor");

while (true) {

if (digitalRead(R1K_input) != HIGH){

delay(delay_time);

break;}

Vout_ohm = analogRead(A0);

new_Vout_ohm = (Vout_ohm*Vref) / 1024 ;

if (new_Vout_ohm < 4.00) {

delay(delay_time);

break;}

}

}

else {

if (R2<1){

lcd.clear();

R2 = R2*1000;

lcd.setCursor(0,0);

41 | P a g e

lcd.print("Resistance");

lcd.setCursor(0,1);

lcd.print(R2);

lcd.setCursor(5,1);

lcd.print(" Ohms");

delay(1000);}

else if (R2>1) {

lcd.clear();

lcd.setCursor(0,0);

lcd.print("Resistance");

lcd.setCursor(0,1);

lcd.print(R2);

lcd.setCursor(5,1);

lcd.print("K Ohms");

delay(1000);

}

}

}

// 1K - 100K

if (digitalRead(R10K_input) == HIGH) {

pinMode(R1K_output,INPUT);

pinMode(R10K_output,OUTPUT);

pinMode(R27K_output,INPUT);

pinMode(R100K_output,INPUT);

digitalWrite(R1K_output, 0);

digitalWrite(R10K_output, 1);

digitalWrite(R27K_output, 0);

digitalWrite(R100K_output, 0);

R2 = 0 ;

for (int i=0; i < 1000; i++) {

42 | P a g e

Vout_ohm = analogRead(A0);

new_Vout_ohm = (Vout_ohm*Vref) / 1024 ;

Vref_div_newVout_ohm = Vref / new_Vout_ohm ;

R2 += (R10K) / (Vref_div_newVout_ohm - 1) ;}

R2 = R2/1000.0 ;

Serial.print("10K ");

Serial.println(new_Vout_ohm);

if (new_Vout_ohm > 4.56) {

lcd.clear();

lcd.setCursor(0,0);

lcd.print("Increase scale /");

lcd.setCursor(0,1);

lcd.print("Change Resistor");

delay(1000);

while (true) {

if (digitalRead(R10K_input) != HIGH){

delay(delay_time);

break;}

Vout_ohm = analogRead(A0);

new_Vout_ohm = (Vout_ohm*Vref) / 1024 ;

if (new_Vout_ohm < 4.56) {

delay(delay_time);

break;}

}

}

else if (new_Vout_ohm < 1.66 && new_Vout_ohm > 0.5 ) {

lcd.clear();

lcd.setCursor(0,0);

lcd.print(" Decrease scale");

delay(1000);

while (true) {

if (digitalRead(R10K_input) != HIGH){

43 | P a g e

delay(delay_time);

break;}

Vout_ohm = analogRead(A0);

new_Vout_ohm = (Vout_ohm*Vref) / 1024 ;

if (new_Vout_ohm > 1.68 ) {

delay(delay_time);

break;}

}

}

else {

lcd.clear();

lcd.setCursor(0,0);

lcd.print("Resistance");

lcd.setCursor(0,1);

lcd.print(R2);

lcd.setCursor(5,1);

lcd.print("K Ohms");

delay(1000);

}}

//

// 100K - 250K

if (digitalRead(R27K_input) == HIGH) {

pinMode(R1K_output,INPUT);

pinMode(R10K_output,INPUT);

pinMode(R27K_output,OUTPUT);

pinMode(R10K_output,INPUT);

digitalWrite(R27K_output, HIGH);

R2 = 0 ;

for (int i=0; i < 1000; i++) {

Vout_ohm = analogRead(A0);

44 | P a g e

new_Vout_ohm = (Vout_ohm*Vref) / 1024 ;

Vref_div_newVout_ohm = Vref / new_Vout_ohm ;

R2 += (R27K) / (Vref_div_newVout_ohm - 1) ;}

R2 = R2/1000.0 ;

Serial.print("27K ");

Serial.println(new_Vout_ohm);

if (new_Vout_ohm > 4.55) {

lcd.clear();

lcd.setCursor(0,0);

lcd.print("Increase scale /");

lcd.setCursor(0,1);

lcd.print("Insert Resistor");

delay(1000);

while (true) {

if (digitalRead(R27K_input) != HIGH){

delay(delay_time);

break;}

Vout_ohm = analogRead(A0);

new_Vout_ohm = (Vout_ohm*Vref) / 1024 ;

if (new_Vout_ohm < 4.550) {

delay(delay_time);

break;}

}

}

else if (new_Vout_ohm < 3.85 && new_Vout_ohm > 0.8) {

lcd.clear();

lcd.setCursor(0,0);

lcd.print(" Decrease scale");

delay(1000);

while (true) {

if (digitalRead(R27K_input) != HIGH){

45 | P a g e

delay(delay_time);

break;}

Vout_ohm = analogRead(A0);

new_Vout_ohm = (Vout_ohm*Vref) / 1024 ;

if (new_Vout_ohm > 3.88 ) {

delay(delay_time);

break;}

}}

else {

lcd.clear();

lcd.setCursor(0,0);

lcd.print("Resistance");

lcd.setCursor(0,1);

lcd.print(R2);

lcd.setCursor(5,1);

lcd.print("K Ohms");

delay(1000);

}}

// 300K - 1M

if (digitalRead(R100K_input) == HIGH) {

pinMode(R1K_output,INPUT);

pinMode(R10K_output,INPUT);

pinMode(R27K_output,INPUT);

pinMode(R100K_output,OUTPUT);

digitalWrite(R100K_output, HIGH);

R2 = 0 ;

for (int i=0; i < 1000; i++) {

Vout_ohm = analogRead(A0);

new_Vout_ohm = (Vout_ohm*Vref) / 1024 ;

Vref_div_newVout_ohm = Vref / new_Vout_ohm ;

46 | P a g e

R2 += (R100K) / (Vref_div_newVout_ohm - 1) ;}

R2 = R2/1000.0 ;

Serial.print("120K ");

Serial.println(new_Vout_ohm);

if (new_Vout_ohm > 4.5) {

lcd.clear();

lcd.setCursor(0,0);

lcd.print("Out of Range /");

lcd.setCursor(0,1);

lcd.print("Insert Resistor");

delay(1000);

while (true) {

if (digitalRead(R100K_input) != HIGH){

delay(delay_time);

break;}

Vout_ohm = analogRead(A0);

new_Vout_ohm = (Vout_ohm*Vref) / 1024 ;

if (new_Vout_ohm < 4.50) {

delay(delay_time);

break;}

}

}

else if (new_Vout_ohm < 3.55 && new_Vout_ohm > 0.5) {

lcd.clear();

lcd.setCursor(0,0);

lcd.print(" Decrease scale");

delay(1000);

while (true) {

if (digitalRead(R100K_input) != HIGH){

delay(delay_time);

break;}

47 | P a g e

Vout_ohm = analogRead(A0);

new_Vout_ohm = (Vout_ohm*Vref) / 1024 ;

if (new_Vout_ohm > 3.56 ) {

delay(delay_time);

break;}

}}

else {

lcd.clear();

lcd.setCursor(0,0);

lcd.print("Resistance");

lcd.setCursor(0,1);

lcd.print(R2);

lcd.setCursor(5,1);

lcd.print("K Ohms");

delay(1000);

}}

}

void voltmeter() {

float dc = 0 ;

for(int i=0; i<1000; i++) {

dc += (analogRead(A1)*4.85*11/1023);

}

dc = dc / 1000 ;

if (dc == 0 ) {dc += 0 ;}

else if (dc > 0 && dc < 1) {dc += 0 ;}

else if (dc > 1 && dc < 4) {dc += 0.25 ;}

else if (dc >4 && dc < 5) {dc += 0.28;}

else if (dc > 5 && dc < 6) {dc += 0.3;}

else if (dc > 6 && dc < 8) {dc += 0.33;}

else if (dc > 8 && dc < 10) {dc += 0.34;}

else if (dc > 10 && dc < 12) {dc += 0.35;}

48 | P a g e

else if (dc > 12 && dc < 16) {dc += 0.36;}

else if (dc > 16 && dc < 22) {dc += 0.37;}

else if (dc > 22 && dc < 25) {dc += 0.38;}

else {dc += 0.39;}

Serial.println(dc);

// float dc = (analogRead(A1)*4.85*11/1023) ;

if (dc > 0 && dc < 1){

lcd.clear();

lcd.setCursor(0,0);

lcd.print("Voltage is not");

lcd.setCursor(0,1);

lcd.print("in Range !");

delay(1000);}

else {

dc += 0.075 ;

lcd.clear();

Serial.println(dc);

lcd.setCursor(0,1);

lcd.print(dc);

lcd.setCursor(6,1);

lcd.print("volts");}

delay(1000);}

void ammeter(){

float current_mA = 0;

for(int i=0; i<5000; i++) {

current_mA += ina219.getCurrent_mA();}

current_mA = current_mA / 5000.0 ;

if (current_mA <= 0 ) {

lcd.clear();

49 | P a g e

lcd.setCursor(0,0);

lcd.print("Ammeter");

lcd.setCursor(0,1);

lcd.print("Check Probes !");

//delay(1000);

}

else {

lcd.clear();

lcd.setCursor(0,0);

lcd.print("Ammeter");

lcd.setCursor(0,1);

lcd.print(current_mA);

lcd.setCursor(6,1);

lcd.print("mA");

} }

50 | P a g e

## Testing the product Functionality

Testing a multimeter is essential to ensure its functioning. Also by doing those testing, we can find how accurate the multimeter is.

Initial Testing
- At the beginning, it's important to check the product for any faulty components or loose connections. If any such issues are found, they should be fixed promptly to ensure the product works properly as intended. Ignoring these problems may result in the product not functioning as it should.

Output Testing

- Conduct initial testing to ensure proper switching between multimeter mode and power supply mode.
- If switching is successful, set the device to multimeter mode.
- Verify voltmeter functionality and compare readings with a laboratory voltmeter.
- If readings do not match, identify and rectify potential faults.
- Repeat the process for ammeter, ohmmeter, and continuity checker.
- After inspecting the multimeter, switch the mode selection to power supply mode.
- Verify the output of 5V DC voltage.
- If the output is incorrect, identify and address the issue promptly.

## Future Improvements

The pursuit of further improvements in a product is of paramount importance. By continuously enhancing its features, performance, and overall quality, a product can adapt to the changing demands of consumers and stay ahead in a competitive market. Such ongoing refinements foster customer satisfaction, loyalty, and expansion of market share. Moreover, they offer opportunities to rectify shortcomings, optimize resources, and achieve cost efficiencies, contributing to the product's long-term success and sustainability. The following improvements can be done to this product in order to improve the product features and capabilities.

- For PCB, Surface Mounted components can be used instead of through holes. Then, PCB size can be further reduced so that the product size can be more reduced.
- Inside wiring can be reduced so that it is more capable of maintenance.
- 16 bits ADC could be used inside the PCB so that the readings will be more accurate.
- One rotary switch could be used so that it is more user friendly.

51 | P a g e

## User Manual

Introduction

Welcome to the Multimeter user manual! This innovative device is equipped with two-way switch that seamlessly transitions between multimeter and 5V power supply modes, catering to your various needs. The user-friendly design features two rotary switches - one for mode selection and the other for adjusting the ohmmeter's scale. All your readings are displayed clearly through the LED display, ensuring precision and accessibility. Notably, this product boasts a built-in charger, eliminating the need for battery changes and providing uninterrupted usability.

Package Content

✓ | Digital Multimeter with DC Power Supply
✓ | Pair of Banana Cable
✓ | Charging Cable
✓ | User Manual
✓ | Warranty Card

### Instructions for User

- This LED indicates that the product is powered now.
Power On-Off Switch | Mode Selection between Multimeter and Power Supply

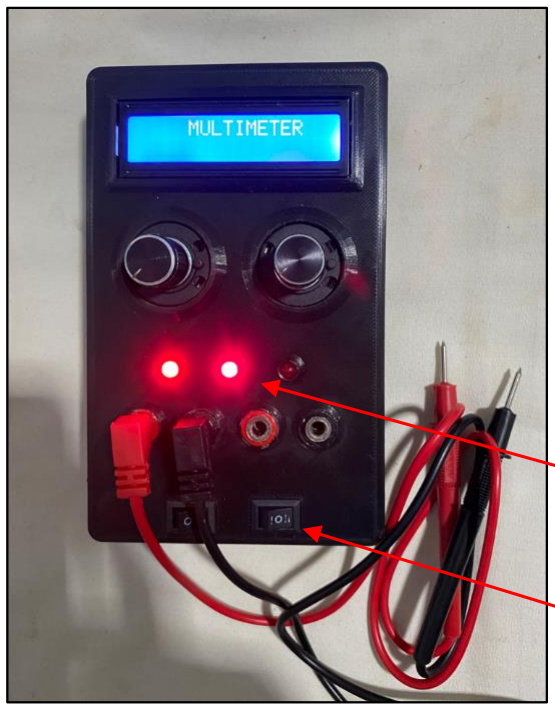
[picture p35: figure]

52 | P a g e
- After switching the second switch it will work as a multimeter.
- This second LED indicates that the device is now in Multimeter Mode and user can see it from the LCD display.

Multimeter Mode indicating LED

Switch is turned on to right side

- This state of rotary switch 1,product works as a voltmeter.

Voltmeter state

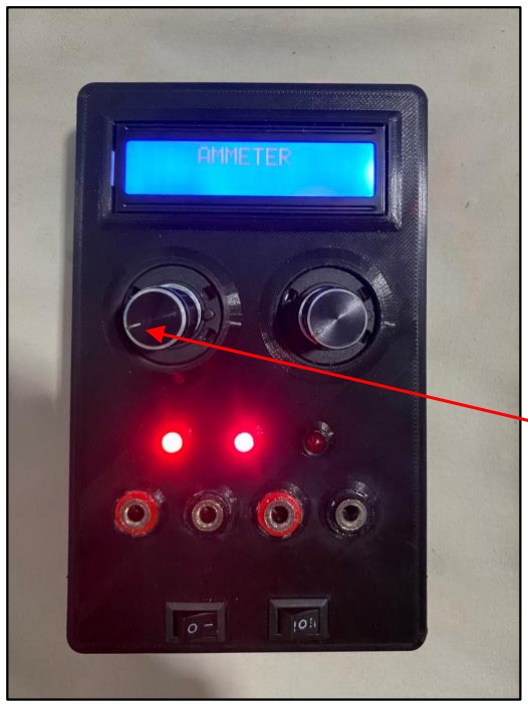
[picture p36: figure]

53 | P a g e
- This state of rotary switch 1, product works as an ammeter.

Ammeter State

- This state of rotary switch 1, product works as an ohmmeter.
- Ohmmeter has four scales and particular scale value can be chosen from rotary switch 2.

Ohmmeter scale rotary switch

Ohmmeter state

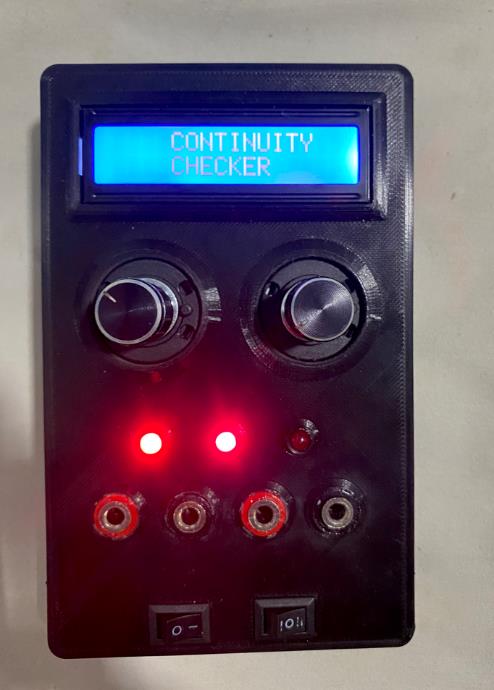
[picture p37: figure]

54 | P a g e
- This state of rotary switch 1, product works as a continuity checker.
- When second switch turn to the left side, product works as a 5V DC power supply.
- This second LED indicates that it is switched to the power supply mode.

Power Supply Mode indicating LED

- When changing the mode of multimeter, user does not have to change the probes. Probes can be put in first two holes accordingly for every state of multimeter.
- When it works as a power supply, user has to put the probes in second two pair of holes accordingly.

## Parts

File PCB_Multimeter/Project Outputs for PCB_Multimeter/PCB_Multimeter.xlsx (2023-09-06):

Comment | Description | Designator | Quantity
22p | Ceramic Capacitor 22pF ±5% 50V C0G Radial | C1, C2 | 2
10n | Ceramic Capacitor 22pF ±5% 50V C0G Radial | C3 | 1
1N4001-T | 1.0 A Rectifier, 15 pF, 50 V, -65 to 150 degC, 2-Pin DO-41 Plastic, RoHS, Tape and Reel | D1 | 1
691214110002 | Serie 2141 - 3.50 mm Horizontal Entry Modular with Rising Cage Clamp WR-TBL, 2 pin | P1, P3 | 2
Header 6 | Header, 6-Pin | P2, P6 | 2
Header 2 | Header, 2-Pin | P4 | 1
Header 4 | Header, 4-Pin | P5 | 1
BC547 | Amplifier Transistor, NPN Silicon, 3-Pin TO-92, Pb-Free, Tape and Reel | Q1 | 1
1M | Res Wirewound 0.1 Ohm 1% 1W ±90ppm/°C Ceramic Hi Temp Sil AXL Thru-Hole Bulk | R1, R11, R12, R13, R14, R15, R16, R17, R18, R20 | 10
1K | Resistor | R2 | 1
10K | Resistor | R3 | 1
10K | Res Wirewound 0.1 Ohm 1% 1W ±90ppm/°C Ceramic Hi Temp Sil AXL Thru-Hole Bulk | R4, R7 | 2
50K | Resistor | R5 | 1
100K | Res Wirewound 0.1 Ohm 1% 1W ±90ppm/°C Ceramic Hi Temp Sil AXL Thru-Hole Bulk | R6 | 1
20K | Res Wirewound 0.1 Ohm 1% 1W ±90ppm/°C Ceramic Hi Temp Sil AXL Thru-Hole Bulk | R8 | 1
20K | Resistor | R9 | 1
100K | Resistor | R10 | 1
G001R1000FE1280 | Res Wirewound 0.1 Ohm 1% 1W ±90ppm/°C Ceramic Hi Temp Sil AXL Thru-Hole Bulk | R16, R19, R22, R23, R24, R25 | 6
220 | Res Wirewound 0.1 Ohm 1% 1W ±90ppm/°C Ceramic Hi Temp Sil AXL Thru-Hole Bulk | R19 | 1
3362P-1-203LF | Resistor | R20, R21, R26, R27 | 4
A30403RNZQ | A Series Rotary Switch, 3 Poles, 4 Positions, 30 deg Angle of Throw, -30 to 85 degC, RoHS | SW1, SW2, SW3 | 3
ATmega328P-PN | 8-bit AVR Microcontroller, 32KB Flash, 1KB EEPROM, 2KB SRAM, 28-pin PDIP, Industrial Grade (-40°C to 105°C) | U1 | 1
FOXSLF/160-20 | Resistance Weld Thru-Hole Crystal, 16 MHz, -20 to 70 degC, 2-Pin THD, RoHS, Bulk | Y1 | 1

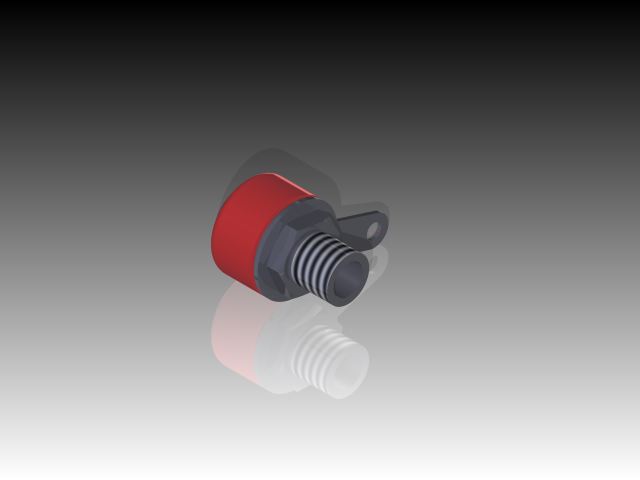
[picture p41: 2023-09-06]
Enclosure/Enclosure Design/Parts/4mm-panel-mount-banana-socket/Renderings/4mm Panel Mount Banana Socket320120109-4008-6xlnxv.jpg

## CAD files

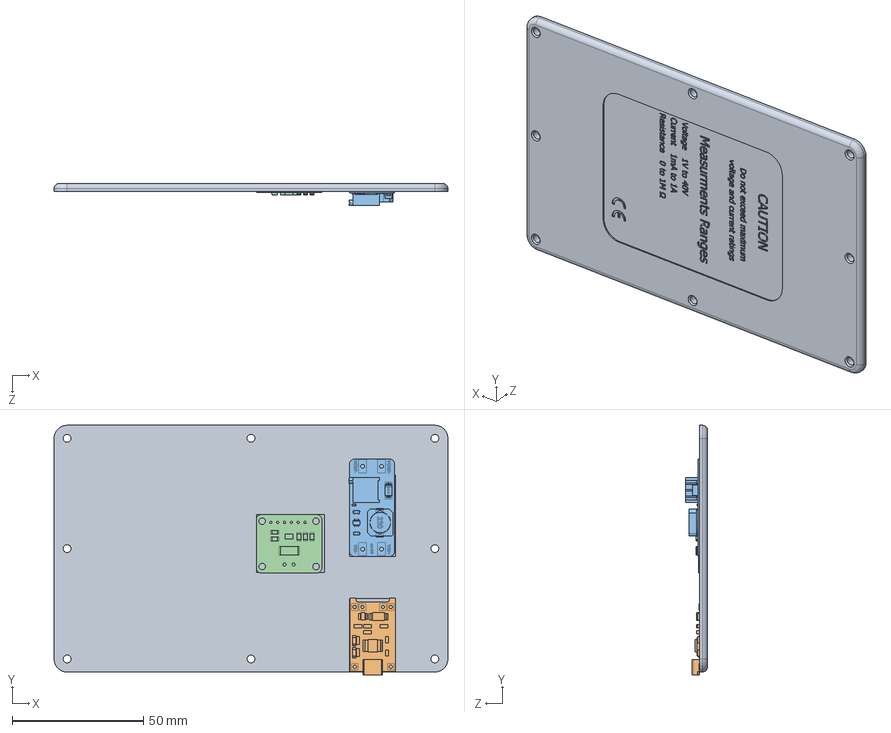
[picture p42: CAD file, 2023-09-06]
Enclosure/Enclosure Design/Finalized/New Assembly/Back Assembly.SLDASM
150.0 x 95.0 x 8.45 mm
tp4056 micro usb 18650 charger
MT3608 Converter
CJMCU-219 INA219.step

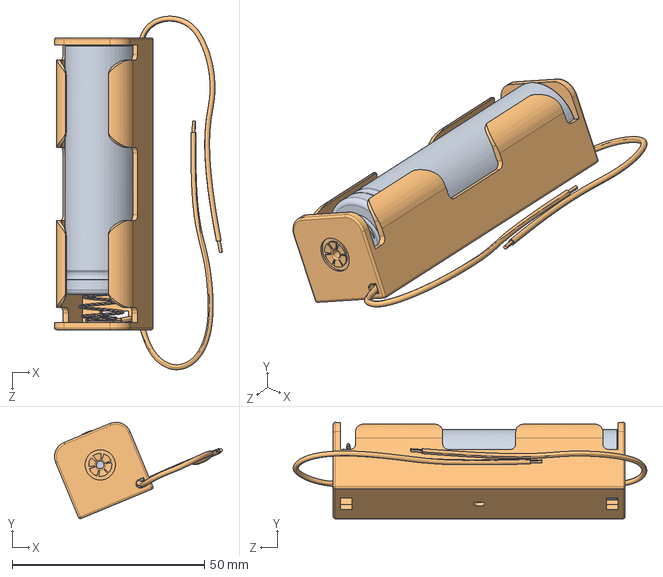
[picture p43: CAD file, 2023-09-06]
Enclosure/Enclosure Design/Parts/18650-battery-holder/Assem battery.SLDASM
43.7 x 25.1 x 92.0 mm
18650 Battery Holder.step

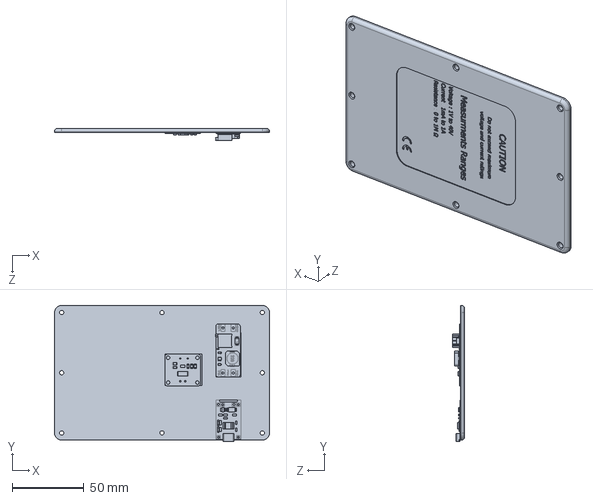
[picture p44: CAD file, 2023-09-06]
Enclosure/Enclosure Design/Finalized/Back Assembly.SLDPRT
150.0 x 95.0 x 8.45 mm

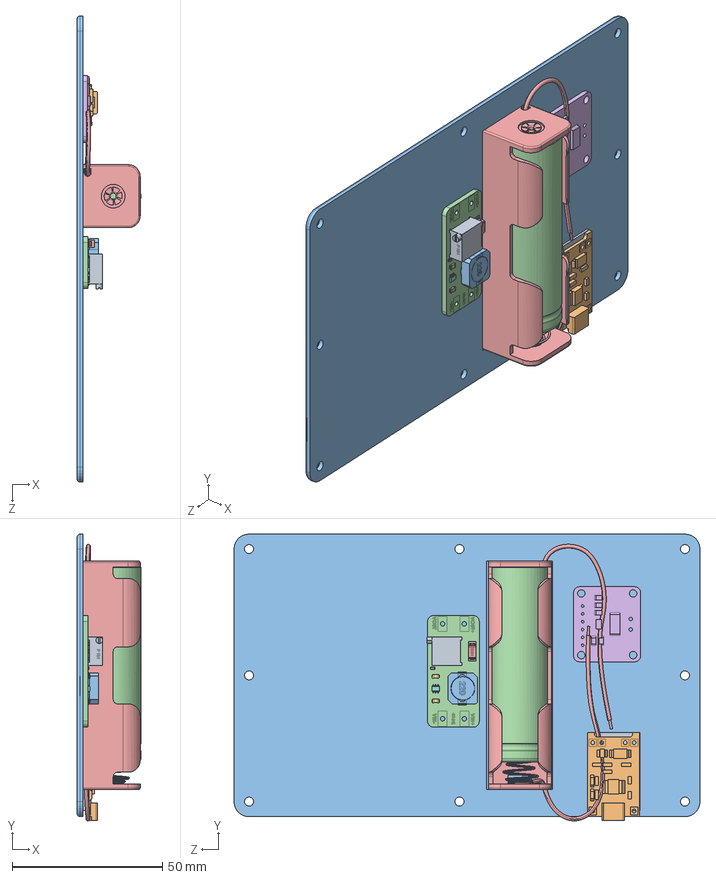
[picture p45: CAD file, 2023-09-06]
Enclosure/Enclosure Design/Parts/tp4056-battery-charger-1.snapshot.2/Assem3.SLDASM
21.2 x 95.4 x 155.0 mm
tp4056 micro usb 18650 charger
MT3608 Converter PCB.STEP
smdS537diode.STEP
tinySMDResistor222.STEP
smdceramiccapacitorbrown.STEP x 2
tinysmdChip6pin.STEP
HorizonatalTrimmerP104.STEP
solder.STEP x 3
smbInductor220.STEP
18650 Battery Holder.step
CJMCU-219 INA219.step

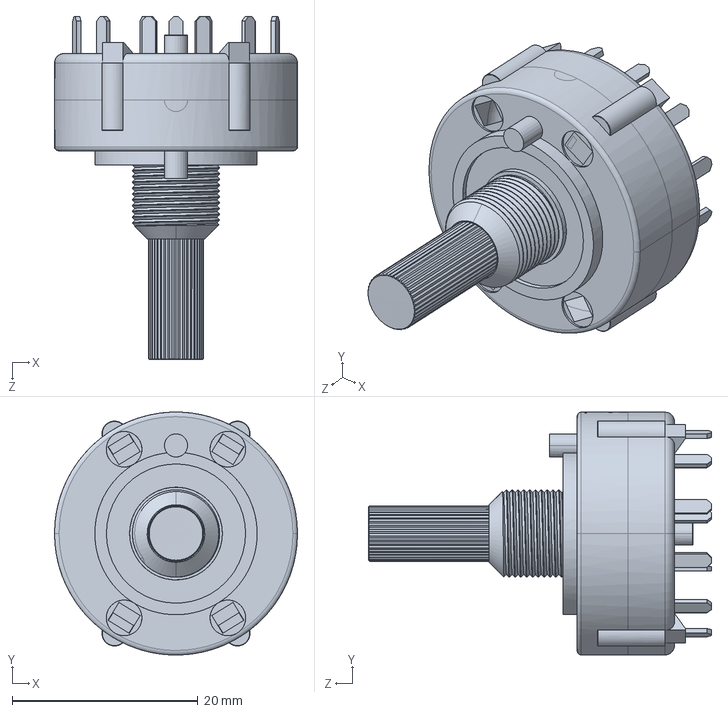
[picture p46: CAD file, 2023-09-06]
Enclosure/Enclosure Design/Parts/rotary-switch-encoder-3-pole-4-throw-3p4t-1.snapshot.2/Assem1.SLDASM
26.2 x 26.2 x 37.0 mm

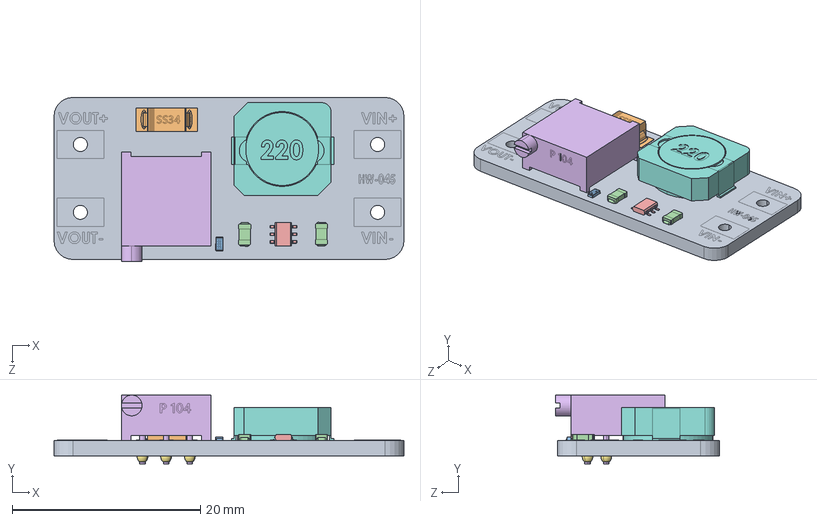
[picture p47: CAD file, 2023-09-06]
Enclosure/Enclosure Design/Parts/18650-battery-holder/MT3608 Converter.STEP.SLDASM
37.1 x 7.30 x 17.4 mm
MT3608 Converter PCB.STEP
smdS537diode.STEP
tinySMDResistor222.STEP
smdceramiccapacitorbrown.STEP x 2
tinysmdChip6pin.STEP
HorizonatalTrimmerP104.STEP
solder.STEP x 3
smbInductor220.STEP

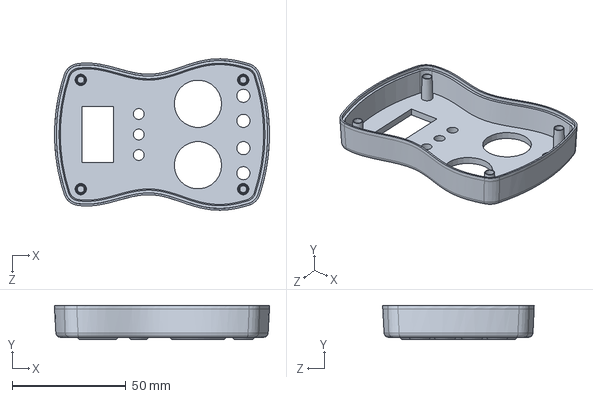
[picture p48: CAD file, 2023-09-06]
Enclosure/Concept Enclosure/display-oled-ssd1306-de-0-96-1.snapshot.6/Lip and Groove/Lip.SLDPRT
94.4 x 15.0 x 66.6 mm

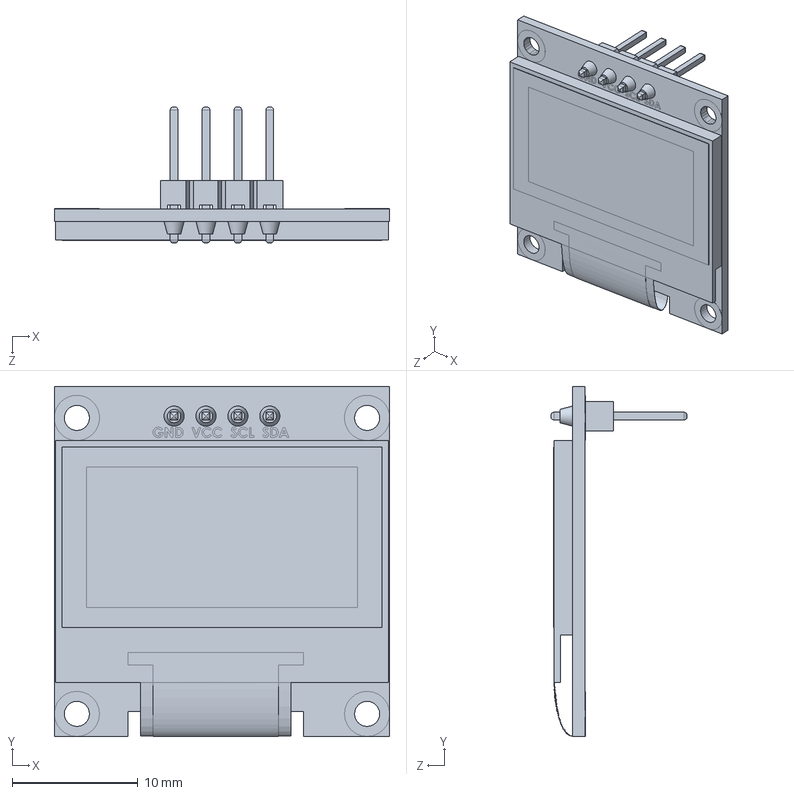
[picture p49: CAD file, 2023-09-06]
Enclosure/Concept Enclosure/display-oled-ssd1306-de-0-96-1.snapshot.6/OLED-128x64-0.96.step.SLDPRT
26.7 x 27.9 x 10.8 mm

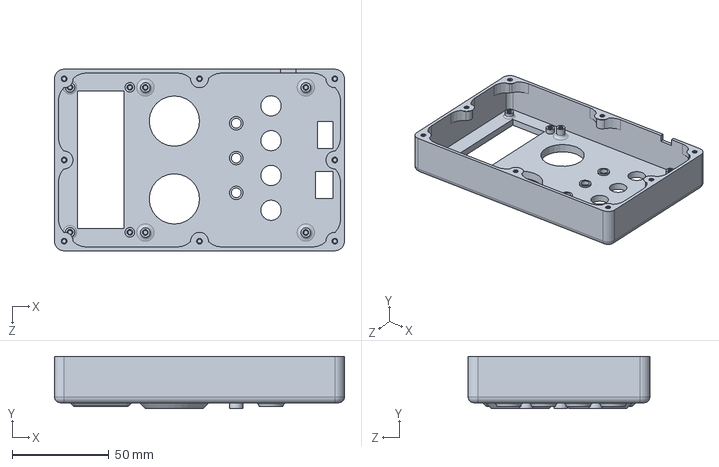
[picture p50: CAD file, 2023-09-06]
Enclosure/Enclosure Design/Finalized/Part1.SLDPRT
150.0 x 27.0 x 94.0 mm

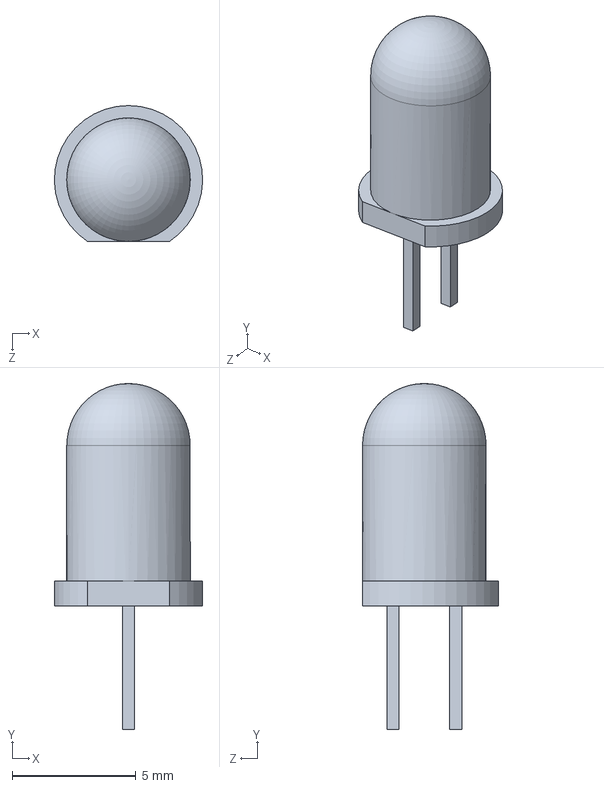
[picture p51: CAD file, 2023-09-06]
Enclosure/Enclosure Design/Parts/18650-battery-holder/18650-battery-holder-1.snapshot.2/LED_5mm_Rot.stp.SLDPRT
6.00 x 14.0 x 5.50 mm

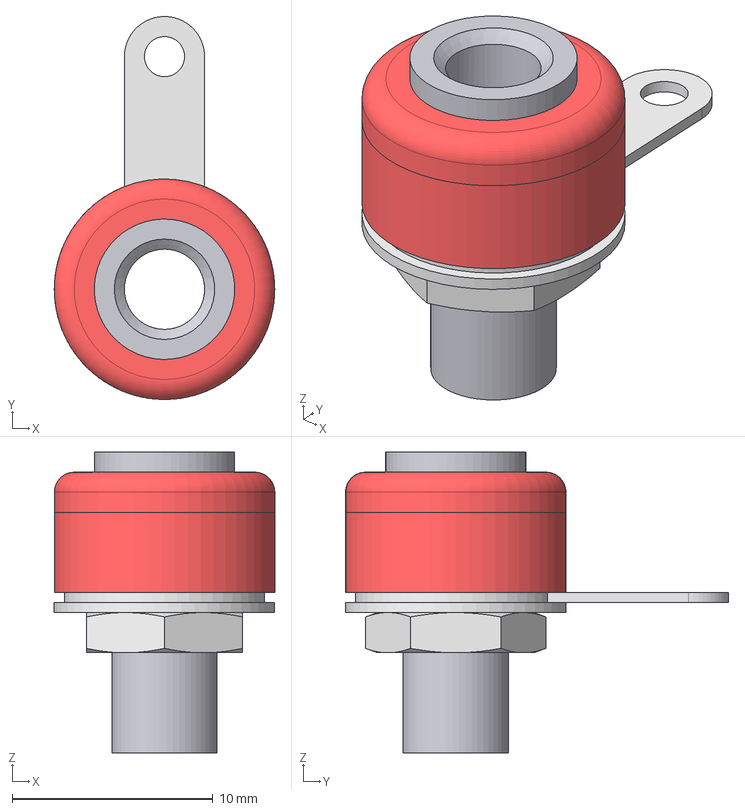
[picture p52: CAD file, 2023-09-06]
Enclosure/Enclosure Design/Parts/4mm-panel-mount-banana-socket/4mm Panel Mount Banana Socket.stp
11.0 x 19.1 x 15.0 mm
Plastic Cap
Plastic Cap top
Socket Tube
Wire Connector
Washer
Connector Nut

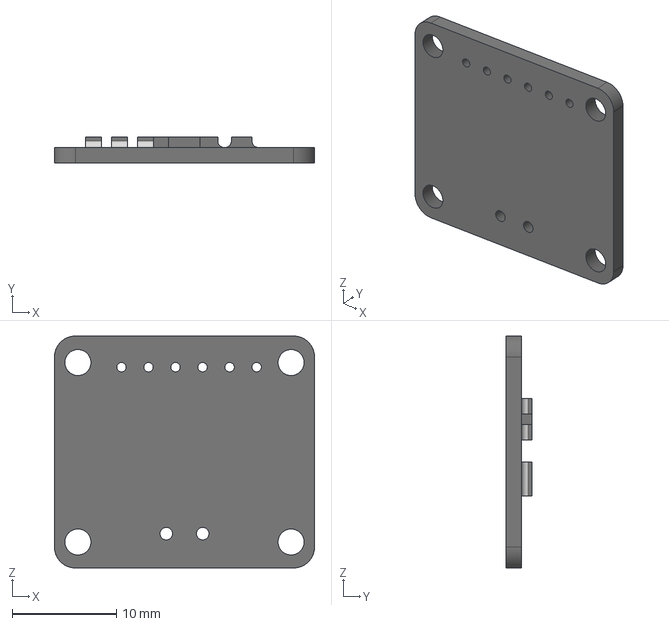
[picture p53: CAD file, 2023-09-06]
Enclosure/Enclosure Design/Parts/ina219-dc-current-sensor-1.snapshot.3/CJMCU-219 INA219 v13.iges
25.0 x 2.50 x 22.3 mm

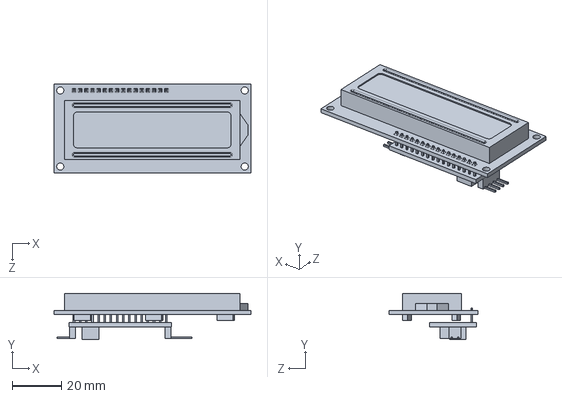
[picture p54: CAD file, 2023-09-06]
Enclosure/Enclosure Design/Parts/LCD/LCDmodule.SLDPRT
80.0 x 18.8 x 36.0 mm

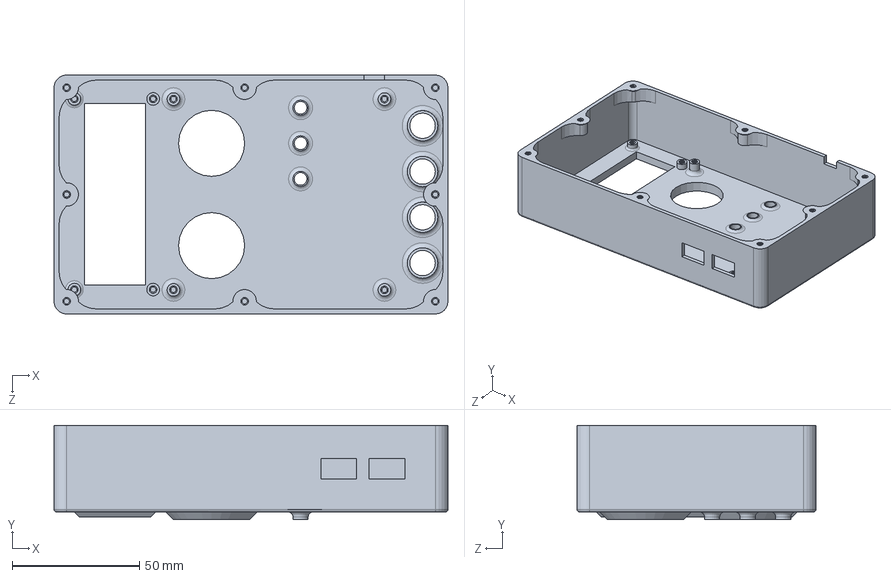
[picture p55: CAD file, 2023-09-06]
Enclosure/Enclosure Design/Parts/Part1_2.SLDPRT
155.0 x 37.0 x 94.0 mm

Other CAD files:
Enclosure/Enclosure Design/Parts/led-red-5mm-2.snapshot.1/BTG_901_BT_001_LED_5mm_Rot/CJMCU-219 INA219.step.SLDPRT
Enclosure/Enclosure Design/Parts/MT3608/CJMCU-219 INA219.step.SLDPRT
Enclosure/Enclosure Design/Parts/Power switch/INTERRUPTOR BASCULANTE.STEP
Enclosure/Enclosure Design/Parts/rocker-switch-25.snapshot.3/RockerSwitch.STEP
Enclosure/Concept Enclosure/display-oled-ssd1306-de-0-96-1.snapshot.6/Lip and Groove/Groove.SLDPRT
Enclosure/Concept Enclosure/display-oled-ssd1306-de-0-96-1.snapshot.6/OLED-128x64-0.96.step
Enclosure/Concept Enclosure/display-oled-ssd1306-de-0-96-1.snapshot.6/Part1.SLDPRT
Enclosure/Enclosure Design/Finalized/Part1.STL
Enclosure/Enclosure Design/Finalized/Part2.SLDPRT
Enclosure/Enclosure Design/Finalized/Part2.STL
Enclosure/Enclosure Design/Finalized/Parts/Part1.SLDPRT
Enclosure/Enclosure Design/Finalized/Parts/Part1.STL
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

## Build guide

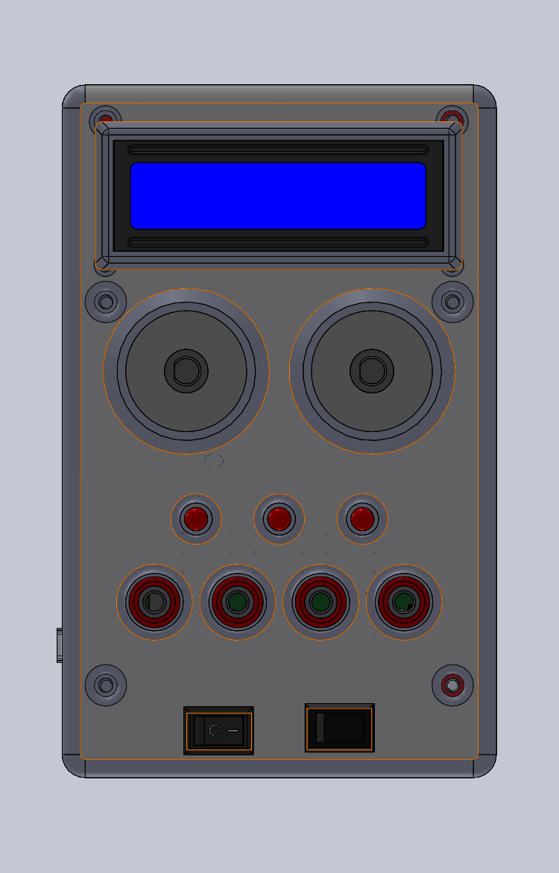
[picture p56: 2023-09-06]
Images/Assembly 1.png

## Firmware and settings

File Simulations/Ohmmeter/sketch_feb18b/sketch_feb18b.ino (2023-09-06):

#include <Wire.h>
#include <LiquidCrystal_I2C.h>

LiquidCrystal_I2C lcd(0x27,16,2); 

int R1K_input = 6;  // 0 - 1K    vdc = 1.75
int R10K_input = 5 ;  // 1K - 95K   vdc = 3.60
int R27K_input = 4 ;  // 95K - 180K   vdc = 3.54
int R100K_input = 3 ; // 205K - 2M    vdc = 3.8

// selecting scale pins
int R1K_output = 13 ;
int R10K_output = 12 ;
int R27K_output = 11;
int R100K_output = 10 ;


// resistors values

float R1K  = 1.2 ;
float R10K  = 10.0 ;
float R27K  = 27.0 ;
float R100K = 120.0 ;


int Vref = 4.85;
float Vout_ohm, new_Vout_ohm, Vref_div_newVout_ohm, R2, Vdc ;

void setup() {
  //analogReference(EXTERNAL);
  lcd.init();
  lcd.backlight();
  Serial.begin(9600) ;
  pinMode(R1K_input,INPUT);
  pinMode(R10K_input,INPUT);
  pinMode(R27K_input,INPUT);
  pinMode(R100K_input,INPUT);

  pinMode(R1K_output,INPUT);
  pinMode(R10K_output,INPUT);
  pinMode(R27K_output,INPUT);
  pinMode(R100K_output,INPUT);

  pinMode(A0, INPUT);  // Vout reading pin
  pinMode(A1, INPUT);
  pinMode(A2, INPUT);
  pinMode(A3, INPUT);
  pinMode(A4, INPUT);
  
  lcd.setCursor(4,0);
  lcd.print("RESISTOR");
  lcd.setCursor(5,1);
  lcd.print("METER");
  delay(2000);

}

void loop() {
    ohmmeter();


    
}


void ohmmeter() {
  
    // 0 - 1K
  if (digitalRead(R1K_input) == HIGH) {
    
    pinMode(R1K_output,OUTPUT);
    pinMode(R10K_output,INPUT);
    pinMode(R27K_output,INPUT);
    pinMode(R100K_output,INPUT);
    digitalWrite(R1K_output, HIGH);
    digitalWrite(R10K_output, 0);
    digitalWrite(R27K_output, 0);
    digitalWrite(R100K_output, 0);


  R2 = 0 ;
  for (int i=0; i < 1000; i++) {
    Vout_ohm = analogRead(A0);
    new_Vout_ohm = (Vout_ohm*Vref) / 1024 ;
    Vref_div_newVout_ohm = Vref / new_Vout_ohm ;
    R2 += (R1K) / (Vref_div_newVout_ohm - 1) ;}
    R2 = R2/1000.0 ;
    
//    Serial.print("1.2K  ");
    Serial.println(new_Vout_ohm);
   
    
    if (new_Vout_ohm > 1.75) {
      lcd.clear();
      lcd.setCursor(0,0); 
      lcd.print(" Increase scale");
      lcd.setCursor(0,1); 
      lcd.print("or Insert Resist");
      while (true) {
        if (digitalRead(R1K_input) != HIGH){
          delay(1000);
          break;}
        Vout_ohm = analogRead(A0);
        new_Vout_ohm = (Vout_ohm*Vref) / 1024 ;
        if (new_Vout_ohm < 4.00) {
          delay(1000);
          break;}
          }       
      }
  
    else {
    if (R2<1){
      lcd.clear();
      Serial.print (R2); Serial.print ("  ");
      R2 = R2*1000;
      Serial.println (R2);
      if (R2 < 10 ) {R2 += R2 * 0.4;}
      else if (10 < R2 && R2 < 250 ) {R2 += R2 * 0.08;}
      else if (250 < R2 && R2 < 600 ) {R2 += R2 * 0.07;}
      else if (600 < R2  && R2 < 800 ) {R2 += R2 * 0.06;}
      else  {R2 += R2 * 0.04;}
      
      lcd.setCursor(0,0);
      lcd.print("Resistance");
      lcd.setCursor(0,1);
      lcd.print(R2);
      lcd.setCursor(5,1);
      lcd.print(" Ohms");
      delay(1000);}
    else if (R2>1) {
      lcd.clear();
      lcd.setCursor(0,0);
      lcd.print("Resistance");
      lcd.setCursor(0,1);
      lcd.print(R2);
      lcd.setCursor(5,1);
      lcd.print("K Ohms");
      delay(1000);
      }
   }
}


//   1K - 95K
  if (digitalRead(R10K_input) == HIGH) {
    
    pinMode(R1K_output,INPUT);
    pinMode(R10K_output,OUTPUT);
    pinMode(R27K_output,INPUT);
    pinMode(R100K_output,INPUT);
    digitalWrite(R1K_output, 0);
    digitalWrite(R10K_output, 1);
    digitalWrite(R27K_output, 0);
    digitalWrite(R100K_output, 0);
    
    R2 = 0 ;
  for (int i=0; i < 1000; i++) {
    Vout_ohm = analogRead(A0);
    new_Vout_ohm = (Vout_ohm*Vref) / 1024 ;
    Vref_div_newVout_ohm = Vref / new_Vout_ohm ;
    R2 += (R10K) / (Vref_div_newVout_ohm - 1) ;}
    R2 = R2/1000.0 ;
    Serial.print("10K  ");
    Serial.println(new_Vout_ohm);
    
    if (new_Vout_ohm > 3.60) {
      lcd.clear();
      lcd.setCursor(0,0); 
      lcd.print(" Increase scale");
      lcd.setCursor(0,1); 
      lcd.print("or Insert Resist");       
      delay(1000);
      while (true) {
        if (digitalRead(R10K_input) != HIGH){
          delay(1000);
          break;}
        Vout_ohm = analogRead(A0);
        new_Vout_ohm = (Vout_ohm*Vref) / 1024 ;
        if (new_Vout_ohm < 4.00) {
          delay(1000);
          break;}
          } 
      }
    else if (new_Vout_ohm < 0.5) {
      lcd.clear();
      lcd.setCursor(0,0); 
      lcd.print(" Decrease scale");     
      delay(1000);
      while (true) {
        if (digitalRead(R10K_input) != HIGH){
          delay(1000);
          break;}
      }
      }
    else {
      lcd.clear();
      lcd.setCursor(0,0);
      lcd.print("Resistance");
      lcd.setCursor(0,1);
      lcd.print(R2);
      lcd.setCursor(5,1);
      lcd.print("K Ohms");
      delay(1000);
    }}
//
  // 99K - 200K
  if (digitalRead(R27K_input) == HIGH) {
    
    pinMode(R1K_output,INPUT);
    pinMode(R10K_output,INPUT);
    pinMode(R27K_output,OUTPUT);
    pinMode(R10K_output,INPUT);
    digitalWrite(R27K_output, HIGH);

    R2 = 0 ;
  for (int i=0; i < 1000; i++) {
    Vout_ohm = analogRead(A0);
    new_Vout_ohm = (Vout_ohm*Vref) / 1024 ;
    Vref_div_newVout_ohm = Vref / new_Vout_ohm ;
    R2 += (R27K) / (Vref_div_newVout_ohm - 1) ;}
    R2 = R2/1000.0 ;
    Serial.print("27K  ");
    Serial.println(new_Vout_ohm);
    
     if (new_Vout_ohm > 3.54) {
      lcd.clear();
      lcd.setCursor(0,0); 
      lcd.print(" Increase scale");
      lcd.setCursor(0,1); 
      lcd.print("or Insert Resist");       
      delay(1000);
      while (true) {
        if (digitalRead(R27K_input) != HIGH){
          delay(1000);
          break;}
        Vout_ohm = analogRead(A0);
        new_Vout_ohm = (Vout_ohm*Vref) / 1024 ;
        if (new_Vout_ohm < 4.00) {
          delay(1000);
          break;}
          } 
      }

    else if (new_Vout_ohm < 3.13) {
      lcd.clear();
      lcd.setCursor(0,0); 
      lcd.print(" Decrease scale");     
      delay(1000);
      while (true) {
        if (digitalRead(R27K_input) != HIGH){
          delay(1000);
          break;}
      }}
    else {
      lcd.clear();
      lcd.setCursor(0,0);
      lcd.print("Resistance");
      lcd.setCursor(0,1);
      lcd.print(R2);
      lcd.setCursor(5,1);
      lcd.print("K Ohms");
      delay(1000);
    }}
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
